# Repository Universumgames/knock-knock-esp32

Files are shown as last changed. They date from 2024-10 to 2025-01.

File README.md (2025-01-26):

# Klap-Klap

- [Klap-Klap](#klap-klap)
  - [Description](#description)
  - [Important files and directories](#important-files-and-directories)
  - [Contributing Setup](#contributing-setup)
  - [Project setup](#project-setup)

URL to repository: https://github.com/Universumgames/knock-knock-esp32

## Description
This project is a simple knock pattern recognizer for a door or chest. The knock pattern is stored on an SD card connected to the ESP32. The knock pattern is recognized by the ESP32 and if the pattern is correct, the door or chest is unlocked. The lock is controlled by a solenoid lock. The project is written in C with the ESP-IDF and uses the PlatformIO IDE. The project is based on the ESP32-C3 microcontroller.

## Important files and directories
- [`documentation/sprint_plan.md`](documentation/sprint_plan.md): Contains the Sprint Plan and detailed description by whom the task was completed
- [`documentation/backlog.md`](documentation/backlog.md): Contains the backlog, a detailed beakdown of the seperate task of this project
- [`src/`](src/): Contains the source code of the project
- [`test/`](test/): Contains the test code of the project
- [`platformio.ini`](platformio.ini): Contains the configuration of the project
- [`README.md`](README.md): Contains the description of the project
- [`LICENSE`](LICENSE): Contains the license of the project
- [`CHANGELOG.md`](CHANGELOG.md): The changelog 
- [`lib/`](lib/): Contains the self written libraries
- [`documentation/`](documentation/): Contains the documentation of the project
- [`datasheets/`](datasheets/): Contains the datasheets for the used components
- [`docker/`](docker/): Contains the docker files to build the platformio environment in a docker container
- [`pinout.txt`](pinout.txt): Contains the pinout of the used microcontroller
- [`pcb/`](pcb/): Contains the pcb files

## Contributing Setup
- install clang-format
  - Debian/Ubuntu: `sudo apt install clang-format`
  - Arch: `sudo pacman -S clang`
  - MacOS: `brew install clang-format`
  - Windows: `pip3 install clang-format`
- configure githooks
  - run `git config core.hooksPath .githooks`
- configure IDE to use clang-format
  - VS Code: install the `Clang-Format` extension (https://marketplace.visualstudio.com/items?itemName=xaver.clang-format)
  - CLion: enable clang-format (https://www.jetbrains.com/help/clion/clangformat-as-alternative-formatter.html)

## Project setup

1. Install VS Code
2. Install PlatformIO extension
3. open PIO Home -> Platforms -> Espressif 32 -> Install (should be installed automatically when opening the project via PlatformIO)
4. building the project by clicking on checkmark in the bottom left corner (when hovering over it, it says: "Build")
5. run tests via the `pio test` command in the terminal

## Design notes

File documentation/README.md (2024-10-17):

# Dokumentation Klopf-Klopf

# Inhalt
- [Product Summary](./produkt.md)
- [Sprint 1](./sprint_01.md)
- [Sprint 2](./sprint_02.md)
- [Sprint 3](./sprint_03.md)
- [Sprint 4](./sprint_04.md)
- [Sprint 5](./sprint_05.md)
- [Backlog](./backlog.md)
- [Sprintplan](./sprint_plan.md)
- [Schaltplan](./assets/circuit.pdf)
- [Timeline](#timeline)

## Timeline
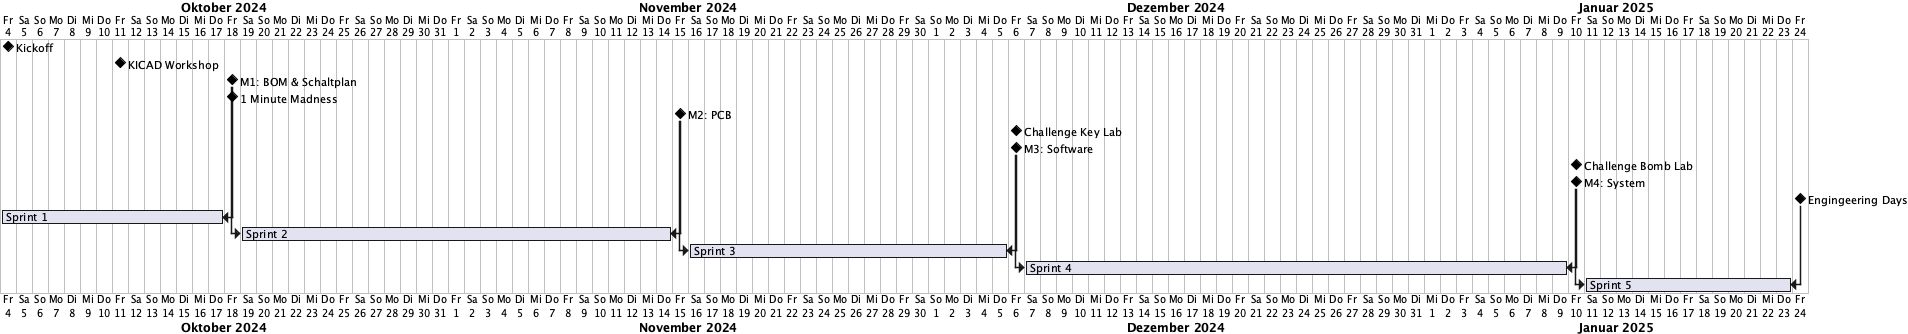
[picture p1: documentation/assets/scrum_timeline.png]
Scrum Timeline


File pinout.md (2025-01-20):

Used Pins:
- Storage: 4,5,6,7
- Onboard LED: 8
- Serial: 20, 21
- USB: (18,19)
- Solenoid: 3
- Piezo: 0
- Buttons: 
  - Up: 2
  - Down: 1
  - Record: 9
  - Delete: 10
  - Play: 19

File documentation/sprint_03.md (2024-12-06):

# Sprint Retro 3

## Kapitän: Jovan Arnaut

## Project Review

### Status

In diesem Sprint haben wir den Algorithmus für die Mustererkennung bzw. Encoden, welches aus dem vorherigen Sprint übrige geblieben war, fertigstellen können. 
Die Mustererkennung wurde auch mit Unit Test versehen und funktioniert soweit einwandfrei. Es ist jedoch noch nötig die Timings zu optimieren und die Thresholds zu justieren, welches eine Aufgabe für den nächsten Sprint sein wird. 
Über die Musteraufnahme und Erkennung hinaus haben wir auch die Musterwiedergabe implementiert. Sie soll später ermöglichen, dass die Muster, die aufgenommen wurden, auch wieder abgespielt werden können, damit sie später vom Nutzer auch gelöscht werden können.
Das Löschen der Muster wurde ebenfalls implementiert.
Der letzte Schritt in diesem Sprint war es die Musterverwaltung zu implementieren. Sie fügt die verschiedenen Funktionen, wie Musterwiedergabe, Löschen und Aufnahme zusammen und ermöglicht es dem Nutzer die aufgenommen Muster zu verwalten. Aufgrund von krankheitsfällen und anderweitigen zeitlich anspruchsvollen Aufgaben konnte die Musterverwaltung nicht vollständig implementiert werden und wird Aufgabe des nächsten Sprints werden.

### Offene Fragen zum Projekt

Im Sprint 3 sind keine weiteren Fragen für den Verlauf des Projektes aufgetreten. 

## Team Retrospektive

### Was hat im Team gut funktioniert?

Die Arbeitsweise im Team funktioniert einwandfrei. Die Aufgabenverteilung und die Zusammenarbeit bei der Besprechung und dem Review der Aufgaben hat gut funktioniert. 

### Was müssen wir an der Arbeitsweise des Teams ändern?

DIe Arbeit im Team hat gut funktioniert, an sich müssen wir nichts ändern. In der richtigen Wirtschaft, hätten wir uns als Team nur eventuell überlegen müssen, dass andere die Aufgaben übernehmen, damit wir durch Krankheitsfälle nicht in Verzug beim Kunden kommen, was jedoch in unserem Rahmen nicht Priorität hat.

### Was sollten wir nicht wiederholen?

In diesem Sprint gab es keine Problematiken, die nicht wiederholt werden dürfen.

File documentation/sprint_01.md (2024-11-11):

# Sprint Retro 1

## Einleitung
Mit dem Produkt Klopf-Klopf wollen wir eine Möglichkeit bieten, klassische Passwörter oder Schlösser durch ein System zur Identifizierung durch eindeutige Klopfmuster zu ersetzen.
Unser Produkt wird in einer Truhe verbaut, um die Funktionsweise handlich demonstrieren zu können. Weitere Informationen zu unserem Produkt sind der [Produktbeschreibung](./produkt.md) zu entnehmen.

---
## Ablauf Sprint 1

In unserem ersten Sprint für unsere Klopfmustererkennung mussten einige Schritte durchlaufen werden, um unsere Vision des Produktes so weit wie möglich zu realisieren. Zunächst haben wir eine detaillierte Projektplanung ([Backlog](./backlog.md)) ausgearbeitet, um einzelne Arbeitsschritte, Anforderungen und [Zeitpläne](./sprint_plan.md) für den weiteren Projektablauf festzulegen. Dies ermöglicht uns einen klaren Ablauf zu definieren und die Entwicklung des Produkts über die Wochen zu organisieren. 

Ein weiterer wesentlicher Bestandteil zu Beginn des Projektes war das Vertrautmachen mit der Entwicklungsumgebung, hier das ESP32-Framework sowie das Toolset [PlatformIO](https://platformio.org). 
Für den ersten Sprint war ebenfalls die Erstellung eines Schaltplans vorgesehen. Der Schaltplan für die Hardwarekomponenten wurde mit Hilfe der Software [KICAD](https://kicad.org) erstellt. Dieser Schaltplan hilft uns im weiteren Projektablauf, um die einzelnen elektronischen Komponenten, wie den Mikrocontroller, das Mikrofon, die LEDs und beispielsweise das Schloss, miteinander zu verbinden. 

In diesem Sprint fingen wir auch bereits mit der Umsetzung des Projektes an, wir bestellten benötigte Komponenten um Prototypen für die Mustererkennung auszuarbeiten. Um die Bauteile auf die Tauglichkeit für das Projekt zu testen und uns mit der ESP-IDF vertraut zu machen, haben wir bereits mit der Entwicklung der Software begonnen. Der zentrale Teil der Software im Sprint 1 war die Programmierung des LED-Drivers sowie des Storage-Drivers. Darüber hinaus implementierten wir die Steuerung für das Schloss unserer Holzbox, welches über ein Solenoid geöffnet und geschlossen wird. 

Um unser Projekt möglichst professionell zu präsentieren, haben wir eine [Präsentation](./one-minute-madness.pdf) erstellt, die unser Projekt in einer Minute anschaulich darstellen soll. Abschließend wurde eine umfassende Dokumentation verfasst, die sämtliche Arbeitsschritte, das Programmieren, die technische Umsetzung sowie die erzielten Ergebnisse beschreibt. Somit liegt unsere zweiwöchige Arbeit als Nachweis dar und dient als Grundlage für mögliche Erweiterungen des Projektes.

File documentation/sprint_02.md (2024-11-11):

# Sprint Retro 2

## Kapitän: Simon Vehreschild

## Project Review

### Status

In diesem Sprint haben wir die Platine entworfen, die Holzbox für unsere Präsentation gebaut, einen Notöffnungsmechanismus verschaltet und die Schloss Status LED implementiert. Die Mustererkennung und das Einspeichern der Muster wurden ebenfalls umgesetzt. Letztere zwei Punkte konnten jedoch aufgrund von zu optimistischer Planung sowie unerwarteten Problemen nicht vollständig abgeschlossen werden und müssen im nächsten Sprint 3 weiter bearbeitet werden.

Außerdem haben wir eine Spannungsversorgungsplatine, sowie eine Operationsverstärkerplatine entworfen, die für erste Testzwecke zum Einsatz gekommen sind.

### Offene Fragen zum Projekt

Im Sprint 2 sind keine weiteren Fragen für den Verlauf des Projektes aufgetreten. 

## Team Retrospektive

### Was hat im Team gut funktioniert?

Sowohl die Aufgabenverteilung als auch die Zusammenarbeit bei der Besprechung und dem Review der Aufgaben hat einwandfrei funktioniert. 
Wir haben uns gut abgestimmt und konnten effizient arbeiten. 
Im Team haben wir uns gegenseitig unterstützt und konnten so die Aufgaben gut bewältigen.

### Was müssen wir an der Arbeitsweise des Teams ändern?

Die Arbeitsweise des Teams verfolgt weiterhin die gesetzen Ziele der folgenden Sprints und muss somit nichts ändern. 

### Was sollten wir nicht wiederholen?

Die Planung der Aufgaben sollte realistischer gestaltet werden, um die Aufgaben besser abschließen zu können. Andererseits stoßen wir auf unerwartete Hindernisse, die nicht immer vorhersehbar sind.

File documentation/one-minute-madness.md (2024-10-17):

# Text für die Präsentation

Sehr geehrte Damen und Herren, bei unserem Produkt handelt es sich um ein Gerät zur Klopfmustererkennung. Der Produktname ist Klopf-Klopf

---

Wir präsentieren Ihnen ein System zur Identifizierung und Türöffnung durch eindeutige Klopfmuster.

Unser Produkt wird über ein revolutionäres Sensorsystem verfügen, mit welchem Klopfmuster erkannt und mit aufgenommenen Mustern verglichen werden können.

Diese Produktidee ist ein universelles Konzept und anwendbar für unzählige andere Anwendungen:

Zum Beispiel: Türschlösser, Tresore, alternative zu Fingerabdrucksensoren, optimal für Kinder

Da sie oft dazu neigen Gegenstände, wie Schlüssel, zu verlieren.

Klopf Klopf ist also die perfekte Alternative für Passwörter und Schlösser, um Ihre Wertsachen sicher aufzubewahren.

---
Wenn Zeit: Prototyp auf Bild zeigen

Vielen Dank für Ihre Aufmerksamkeit

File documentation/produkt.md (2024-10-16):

# Produkt

## Titel des Projekts: Klopf-Klopf (Topic 6 - Team B: Klopfmuster-Erkennung)

## Teammitglieder
- Jovan Arnaut: 1544440 
- Tom Arlt: 1335730
- Simon Vehreschild: 1543175

## Motivation
Ziel dieses Projektes ist es, den Umgang mit dem ESP32 und anderen elektrischen Komponenten zu erlernen und die grundlegende Funktionsweise des Mikrocontrollers zu verstehen. Außerdem wollen wir im Laufe des Projektes die Programmiersprache Assembler nachvollziehen und anwenden können.

## Beschreibung
Mit diesem Produktprototypen soll es möglich sein Klopfmuster zu erkennen und darauf zu reagieren. Es sollen Klopfmuster eingespeichert werden können, welche dann vom ESP32 wiedererkannt werden. Bei Erkennung eines eingespeicherten Klopfmusters soll das Schloss entriegelt werden. Da es für die Präsentation schwierig werden würde eine Tür zu verwenden, werden wir die Kopfmustererkennung nutzen, um eine Truhe zu entriegeln.

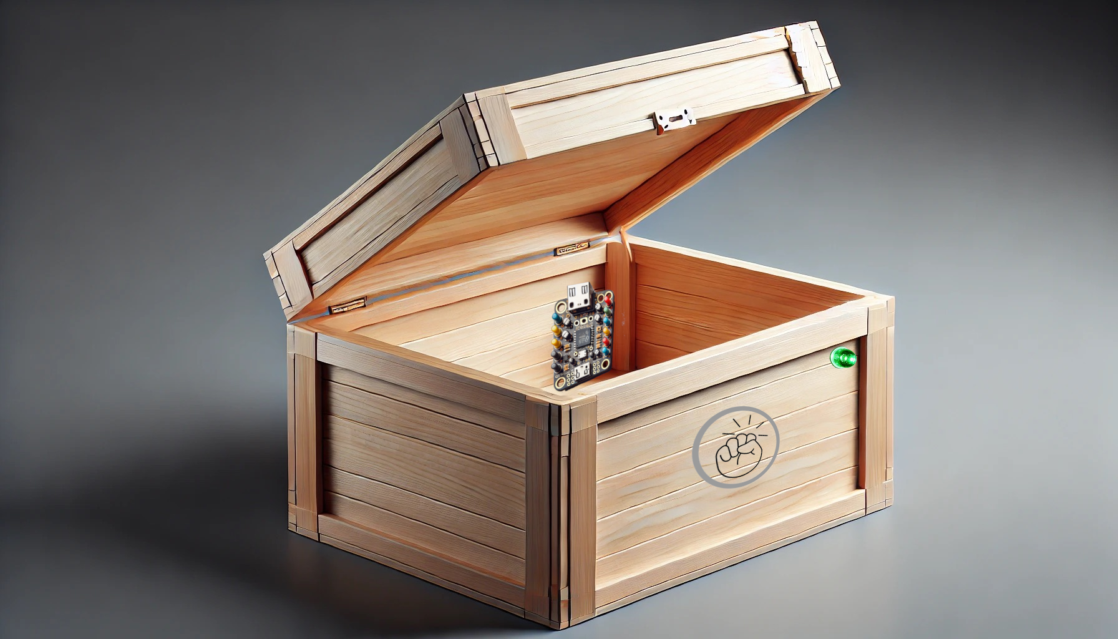
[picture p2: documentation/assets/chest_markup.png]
Produkt Abbildung


## Evaluation
Unser Produkt, die Klopfmustererkennung, ist in einer Truhe verbaut, die entriegelt wird, wenn das richtige Klopfmuster erkannt wird. Die Truhe ist mit einem Solenoid Schloss versehen, das durch den ESP32 gesteuert wird.
Die Funktionen, die bei unserem Produkt ausprobierbar sind, beinhalten das Einspeichern von neuen Klopfmustern, das Löschen von gespeicherten Klopfmustern, das Erkennen von Klopfmustern und das daraus folgende Öffnen des Schlosses. Das Schloss soll durch jeden geöffnet werden können, der eine der eingespeicherten Klopfmuster kennt. 

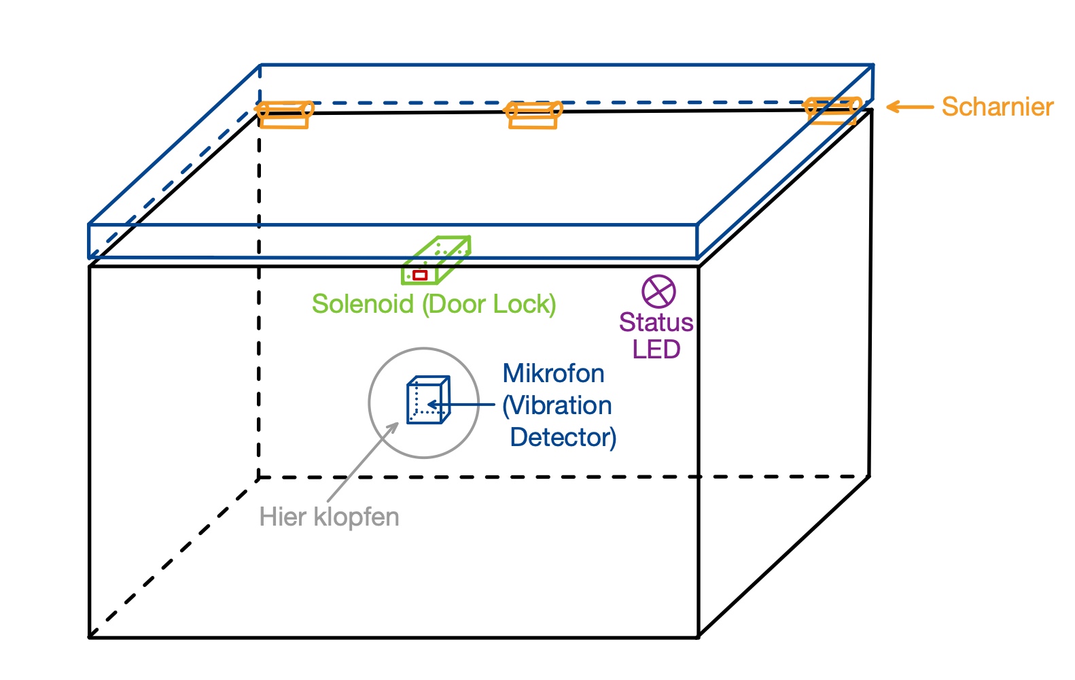
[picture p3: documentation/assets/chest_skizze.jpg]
Produkt Skizze


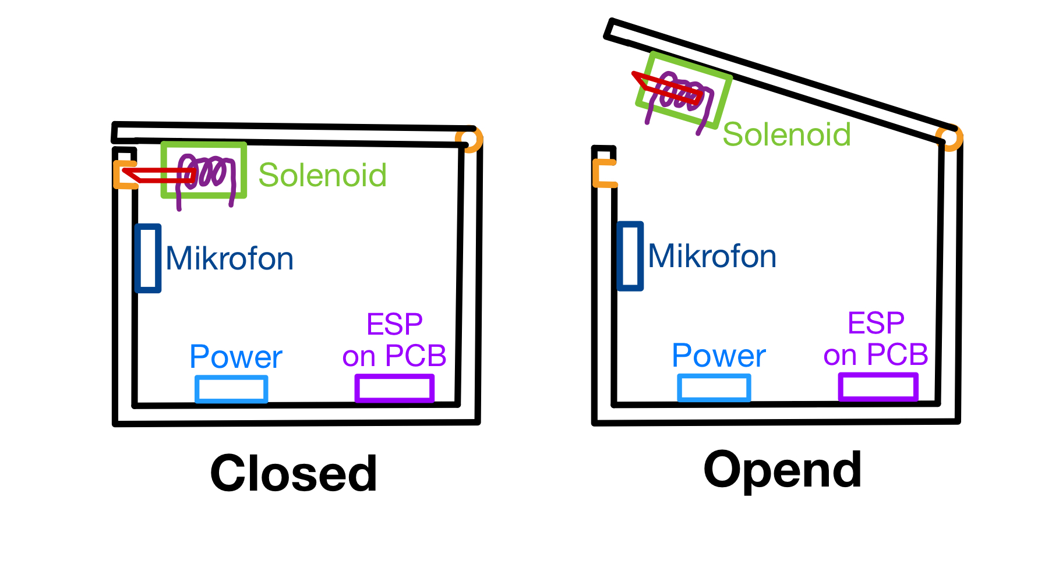
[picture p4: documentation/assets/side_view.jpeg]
Seitenansicht


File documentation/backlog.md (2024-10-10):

# Backlog
### Inhaltsverzeichnis

- [Backlog](#backlog)
    - [Inhaltsverzeichnis](#inhaltsverzeichnis)
    - [Erster Entwurf](#erster-entwurf)
  - [Aufgabe: Planung des Projekts](#aufgabe-planung-des-projekts)
    - [Beschreibung](#beschreibung)
- [Software Backlog](#software-backlog)
  - [Aufgabe: Vertrautmachen mit der Entwicklungsumgebung](#aufgabe-vertrautmachen-mit-der-entwicklungsumgebung)
    - [Beschreibung](#beschreibung-1)
  - [Aufgabe: Umsetzung der Mustererkennung](#aufgabe-umsetzung-der-mustererkennung)
    - [Beschreibung](#beschreibung-2)
    - [Definition von „Spaß“](#definition-von-spaß)
    - [Akzeptanzkriterien](#akzeptanzkriterien)
  - [Aufgabe: Muster einspeichern](#aufgabe-muster-einspeichern)
    - [Beschreibung](#beschreibung-3)
    - [Definition von „Spaß“](#definition-von-spaß-1)
    - [Akzeptanzkriterien](#akzeptanzkriterien-1)
  - [Aufgabe: Musteraufnahme](#aufgabe-musteraufnahme)
    - [Beschreibung](#beschreibung-4)
    - [Akzeptanzkriterien](#akzeptanzkriterien-2)
  - [Aufgabe: Muster löschen](#aufgabe-muster-löschen)
    - [Beschreibung](#beschreibung-5)
    - [Akzeptanzkriterien](#akzeptanzkriterien-3)
  - [Aufgabe: Schloss öffnen](#aufgabe-schloss-öffnen)
    - [Beschreibung](#beschreibung-6)
    - [Akzeptanzkriterien](#akzeptanzkriterien-4)
  - [Aufgabe: Musterverwaltung](#aufgabe-musterverwaltung)
    - [Beschreibung](#beschreibung-7)
    - [Akzeptanzkriterien](#akzeptanzkriterien-5)
  - [Aufgabe: Musterwiedergabe](#aufgabe-musterwiedergabe)
    - [Beschreibung](#beschreibung-8)
    - [Definition von „Spaß“](#definition-von-spaß-2)
    - [Akzeptanzkriterien](#akzeptanzkriterien-6)
  - [Aufgabe: Schloss Status LED](#aufgabe-schloss-status-led)
    - [Beschreibung](#beschreibung-9)
    - [Definition von „Spaß“](#definition-von-spaß-3)
    - [Akzeptanzkriterien](#akzeptanzkriterien-7)
  - [Aufgabe: Storage Driver](#aufgabe-storage-driver)
    - [Beschreibung](#beschreibung-10)
    - [Akzeptanzkriterien](#akzeptanzkriterien-8)
  - [Aufgabe: LED-Driver](#aufgabe-led-driver)
    - [Beschreibung](#beschreibung-11)
    - [Akzeptanzkriterien](#akzeptanzkriterien-9)
- [Hardware Backlog](#hardware-backlog)
  - [Aufgabe: Anfertigung der Holzbox](#aufgabe-anfertigung-der-holzbox)
    - [Beschreibung](#beschreibung-12)
    - [Definition von „Spaß“](#definition-von-spaß-4)
    - [Akzeptanzkriterien](#akzeptanzkriterien-10)
  - [Aufgabe: Solenoid (Door-Lock)](#aufgabe-solenoid-door-lock)
    - [Beschreibung](#beschreibung-13)
    - [Akzeptanzkriterien](#akzeptanzkriterien-11)
  - [Aufgabe: Drucktaster](#aufgabe-drucktaster)
    - [Beschreibung](#beschreibung-14)
    - [Akzeptanzkriterien](#akzeptanzkriterien-12)
  - [Aufgabe: RGB-LED (WS2812b)](#aufgabe-rgb-led-ws2812b)
    - [Beschreibung](#beschreibung-15)
    - [Definition von „Spaß“](#definition-von-spaß-5)
    - [Akzeptanzkriterien](#akzeptanzkriterien-13)
  - [Aufgabe: Notöffnungsmechanismus](#aufgabe-notöffnungsmechanismus)
    - [Beschreibung](#beschreibung-16)
    - [Akzeptanzkriterien](#akzeptanzkriterien-14)
  - [Aufgabe: Mikrofon](#aufgabe-mikrofon)
    - [Beschreibung](#beschreibung-17)
    - [Definition von „Spaß“](#definition-von-spaß-6)
    - [Akzeptanzkriterien](#akzeptanzkriterien-15)
  - [Aufgabe: Spannungsversorgung](#aufgabe-spannungsversorgung)
    - [Beschreibung](#beschreibung-18)
    - [Akzeptanzkriterien](#akzeptanzkriterien-16)
  - [Aufgabe: Platine entwerfen](#aufgabe-platine-entwerfen)
    - [Beschreibung](#beschreibung-19)
    - [Akzeptanzkriterien](#akzeptanzkriterien-17)
  - [Aufgabe: Fertigstellen des Systems](#aufgabe-fertigstellen-des-systems)
    - [Beschreibung](#beschreibung-20)
    - [Akzeptanzkriterien](#akzeptanzkriterien-18)
  - [Aufgabe: Erstellen eines Videos](#aufgabe-erstellen-eines-videos)
    - [Beschreibung](#beschreibung-21)
    - [Akzeptanzkriterien](#akzeptanzkriterien-19)
  - [Aufgabe: Erstellen des Kaufpitch](#aufgabe-erstellen-des-kaufpitch)
    - [Beschreibung](#beschreibung-22)
    - [Akzeptanzkriterien](#akzeptanzkriterien-20)

### Erster Entwurf

Features:
- Software:
    - [Mustererkennung](#aufgabe--umsetzung-der-mustererkennung)
    - [Muster einspeichern](#aufgabe--muster-einspeichern)
    - [Musteraufnahme](#aufgabe--musteraufnahme)
    - [Muster löschen](#aufgabe--muster-löschen)
    - [Schloss öffnen](#aufgabe--schloss-öffnen)
    - [Musterverwaltung](#aufgabe--musterverwaltung)
    - [Schloss Status LED](#aufgabe--schloss-status-led)
    - Dependency Features
      - [Musterwiedergabe](#aufgabe--musterverwaltung)
      - [Storage Driver](#aufgabe--storage-driver)
      - [LED Driver](#aufgabe--led-driver)

## Aufgabe: Planung des Projekts

### Beschreibung
Die Planung des Projekts umfasst die Aufteilung der Aufgaben in Sprints, die Zuweisung von Verantwortlichkeiten und die Schätzung des Zeitaufwands für die einzelnen Aufgaben. Sie dient dazu, das Projekt in überschaubare Teilaufgaben zu gliedern, erste Gedanken zu Umsetzung und diese im Nachhinein zu erleichtern.

## Aufgabe: Erstellen der Dokumentation

### Beschreibung
Kontinuierlich wird der Fortschritt des Projektes dokumentiert und die Dokumentation für jeden Sprint finalisiert.

### Akzeptanzkriterien
Die vollständige Dokumentation liegt vor.

## Aufgabe: Erstellen der 1 Minute Madness (PowerPoint)

### Beschreibung
In der "1 Minute Madness" haben wir genau eine Minute unsere Produktidee zu präsentieren. Dafür wollen wir eine PowerPoint-Präsentation erstellen.

### Akzeptanzkriterien
Die 1 Minute Madness ist präsentiert und im Vorhinein wurde eine PowerPoint-Präsentation erstellt.

# Software Backlog

## Aufgabe: Vertrautmachen mit der Entwicklungsumgebung 

### Beschreibung
Die Entwicklungsumgebung ist bisher für uns noch unbekannt, daher benötigt unser Team eine gewisse Zeit sich mit den Möglichkeiten vertraut zu machen.

## Aufgabe: Umsetzung der Mustererkennung

### Beschreibung
Die Mustererkennung sollte ähnliche Muster zuordnen können und ggf. bei zu großen Abweichungen des abgespeicherten Musters dies ausgeben. Die Schwierigkeit liegt dabei in der Verarbeitung des Mikrofonsignals und der Erkennung der Änderungen dieses Signal durch ein Klopfen. Anschließend soll das Muster mit den gespeicherten Mustern verglichen werden. Falls das Muster einem gespeicherten ähnelt, soll dies durch ein Öffnen des Verriegelungsmechanismus und der Grünen-LED zum Ausdruck gebracht werden.

### Definition von „Spaß“
Dies ist die Hauptherausforderung des gesamten Projekts und erfordert einen kreativen Lösungsansatz und eine gute Signalverarbeitung, da zwei Muster nie 100% identisch sein können.

### Akzeptanzkriterien
Der Mustererkennungs-Algorithmus soll in der Lage sein, das Muster durch das Rauschen zu erkennen und mit den eingespeicherten Mustern zu vergleichen. Anschließend soll bei einer gewissen Ähnlichkeit der Verriegelungsmechanismus und die Grüne-LED angesteuert werden können.

## Aufgabe: Muster einspeichern

### Beschreibung
Um die Muster zu speichern, müssen diese in ein simples und effizientes Format umgewandelt werden. Die Muster sollen in Dateien gespeichert werden, hierfür muss ein de-/serialisierungs-Algorithmus für die Muster geschrieben werden.

### Definition von „Spaß“
Wurde ein neues Muster aufgenommen, besteht die Herausforderung darin, dieses in ein Möglichst effizientes Format zu konvertieren und zu speichern. Dies garantiert eine schnelle und effiziente Mustererkennung und erfordert einiges an Kreativität und technischem Verständnis.

### Akzeptanzkriterien
Muster können gespeichert und abgerufen werden. Die Muster sind in einem effizienten Format gespeichert und können schnell und einfach abgerufen werden.

## Aufgabe: Musteraufnahme

### Beschreibung
Mit der Musteraufnahme ist das Aufnehmen und Filtern des Sensor-Signals gemeint. Das Mikrofon-Signal muss gefiltert und in ein verarbeitbares Format umgewandelt werden. Dieses Muster wird anschließend in der Mustererkennung sowie der Musterspeicherung verwendet. Für die Musteraufnahme kommt ein von der Musterverwaltung unabhängiger Knopf zum Einsatz.

### Akzeptanzkriterien
Störgeräusche wie Rauschen und andere Umgebungsgeräusche müssen gefiltert werden. Das Muster muss in einem effizienten Format als struct gespeichert werden und kann anschließend in der Mustererkennung verwendet werden um Muster zu vergleichen und einfacher zu speichern.

## Aufgabe: Muster löschen

### Beschreibung
Um die gespeicherten Muster von dem Flash-Speicher des ESP oder der SD-Karte entfernen zu können, muss eine Funktion im Speicher-Management implementiert werden, die das Löschen gespeicherter Mustert ermöglicht.

### Akzeptanzkriterien
Muster können nach dem Speichern auch gelöscht werden um neuen Speicherplatz zu schaffen.

## Aufgabe: Schloss öffnen

### Beschreibung
Die Kiste soll im Ruhezustand verschlossen und verriegelt sein. Sobald es (durch die Eingabe des korrekten Klopfmusters) gewünscht wird, soll das Solenoid die Falle (des Schlosses) zurück ziehen. Da das Solenoid nicht direkt durch den ESP mit Strom versorgt werden kann, kommt hier ein Relais zum Einsatz, welches mittels ESP angesteuert werden soll.

### Akzeptanzkriterien
Das Solenoid muss noch nicht angesteuert werden können. Es reicht aus, wenn das Relais umgeschaltet werden kann.

## Aufgabe: Musterverwaltung 

### Beschreibung
Die Musterverwaltung ermöglicht die Auswahl (Navigation) zwischen den einzelnen gespeicherten Mustern. Für die Muster gibt es zwei Funktionen: Muster löschen, Musterwiedergabe. Für die Musterverwaltung gibt es 4 Knöpfe: Vor, Zurück, Muster löschen, Musterwiedergabe. (Für das Aufnehmen von Mustern gibt es einen eigenständigen Knopf -> Musteraufnahme)

### Akzeptanzkriterien
Die Verwaltung sollte die einwandfreie Navigation durch die gespeicherten Muster ermöglichen, sowie den Aufruf der oben genannten Funktionen ausführen.

## Aufgabe: Musterwiedergabe

### Beschreibung

Die Musterwiedergabe soll die Möglichkeit bieten, ein gespeichertes Muster wiederzugeben. Dies ist wichtig, um die gespeicherten Muster zu überprüfen und zu löschen. Die Musterwiedergabe wird durch einen Drucktaster ausgelöst, der unabhängig von der Musterverwaltung ist. 

### Definition von „Spaß“
Interessant ist hier das gespeicherte Format eines Musters wieder in eine wiedererkennbare Form zu bringen und dieses Muster wiederzugeben.
Hierfür eine passende Darstellung zu finden und das Muster wiederzugeben ist eine kreative Herausforderung.

### Akzeptanzkriterien
Abgespeicherte Muster können wiedergegeben werden und sind in einer verständlichen Form dargestellt.

## Aufgabe: Schloss Status LED

### Beschreibung
An der Truhe befindet sich eine adressierbare LED (WS2812b) soll den Status des Schlosses anzeigen.
Die grundlegenden Status sind:
- Rot: Schloss ist verriegelt
- Grün: Schloss ist entriegelt
- Blau: aktuell wird ein Muster aufgenommen
- Orange: Muster ist fast korrekt
- Weiß: Fehlerfall

Unter Umständen müssen diese Status noch erweitert werden um weitere Informationen anzuzeigen, die erst im Laufe der Entwicklung aufgedeckt 
werden.

### Definition von „Spaß“
Interessant ist hier die Ansteuerung der LED anhand des Datenblatts zu analysieren und dieses eigene Protokoll im Code für die ESP-IDF zu entwickeln.

### Akzeptanzkriterien
Die LED zeigt den korrekten Status des Schlosses an.

## Aufgabe: Storage Driver

### Beschreibung
Der Storage Driver soll die Kommunikation zwischen Datenspeicher (on-board oder SD-Card) und dem ESP32 dienen.

### Akzeptanzkriterien
Dateien können korrekt erstellt und gelöscht werden.

## Aufgabe: LED-Driver

### Beschreibung
Der LED-Driver dient dazu die adressierbaren LEDs anzusteuern. Hierbei soll der Typ WS2812b verwendet werden und einfach, vergleichbar zu der FastLED Library, angesteuert werden können.

### Akzeptanzkriterien
Die LEDs können angesteuert werden und die Farbe wird für jede LED korrekt eingestellt.

# Hardware Backlog

## Aufgabe: Anfertigung der Holzbox

### Beschreibung
Um eine Tür zu demonstrieren, verwenden wir eine Box aus Holz, welche einen Doppelboden besitzt. Die Hardware-Komponenten werden in der verschlossenen Holzbox untergebracht. Der Doppelboden kann für die sichere und ordentliche Verkabelung der Komponenten genutzt werden, um Platz zu sparen und die Verdrahtung zu verstecken. 

### Definition von „Spaß“
Die Möglichkeit, ein eigenes und funktionales Produkt zu schaffen, trägt positiv zum Projekt bei. Der Prozess des Entwurfes und der Konstruktion der Holzbox bereichern die handwerklichen Fähigkeiten, die damit gefördert werden. 

### Akzeptanzkriterien
Die Aufgabe ist erledigt, wenn die Holzbox fertig montiert vorliegt und die jeweiligen Komponenten in der Box verbaut verden könnten. 

## Aufgabe: Solenoid (Door-Lock)

### Beschreibung
Um die Holzbox öffnen und schließen zu können wird ein Solenoid-Magnet als mechanischer Türverschluss verwendet. Der Mikrocontroller sendet ein Signal an das Solenoid, um die Tür jeweils zu verschließen oder zu entriegeln. Um das Solenoid vernünftig an die Holzbox anbringen zu können, wird eine Kerbe in die Wand gefräst. Die Ansteuerung des Solenoids erfolgt über ein Relais.

### Akzeptanzkriterien
Die Aufgabe ist erledigt, wenn die Tür mithilfe des Solenoids ohne Störungen verschlossen und entriegelt werden kann.

## Aufgabe: Drucktaster

### Beschreibung
Es werden mehrere Drucktaster eingerichtet, um Funktionen wie das Speichern, Navigieren und Löschen von Klopfmustern zu ermöglichen. Die jeweiligen Taster sind mit dem Mikrocontroller verbunden, der letztendlich die Eingaben verarbeitet. Die Taster müssen hardwaretechnisch entprellt werden.

### Akzeptanzkriterien
Die Aufgabe gilt als erledigt, wenn die Drucktaster am Gehäuse befestigt sind und ihre Funktionen in der Software erfüllen. 

## Aufgabe: RGB-LED (WS2812b)

### Beschreibung
Um den Status unseres Schlosses anzuzeigen, verwenden wir eine RGB-LED (WS2812b), welche wir zuvor konfigurieren. 

### Definition von „Spaß“
Die Herausforderung, die Ansteuerung der LED zu untersuchen und das entsprechende Datenblatt zu analysieren, um ein eigenes Protokoll im Code für die ESP_IDF zu erstellen.

### Akzeptanzkriterien
Die LED zeigt den korrekten Status des Schlosses an.

## Aufgabe: Notöffnungsmechanismus

### Beschreibung
Ein 12V-Kabel wird zum Solenoid geführt, um im Fehlerfall eine Notöffnung der Tür zu ermöglichen. Dies könnte durch einen Taster oder Schalter erfolgen, der unabhängig vom Mikrocontroller funktioniert. 

### Akzeptanzkriterien
Wenn das Schloss zu jeder Zeit oder bei Notfällen unabhängig vom Microcontroller geöffnet werden kann. Das Notöffnen des Schlosses sollte auch bei nicht vorhandener Platine und bei Softwareabsturz möglich sein.

## Aufgabe: Mikrofon

### Beschreibung
Es wird ein Mikrofon installiert, um die Klopfgeräusche und das dazugehörige Muster aufzuzeichnen. Das Mikrofon ist mit dem Microcontroller verbunden, welcher die Klopfgeräusche letztendlich analysiert, um ein Muster zu erkennen. 

### Definition von „Spaß“
Interessant ist hier die Ansteuerung des Mikrofons anhand des Datenblatts zu analysieren und die aufgenommenen Klopfgeräusche aufzunehmen und zu verwerten. 

### Akzeptanzkriterien
Die Funktion ist gegeben, wenn das Klopfgeräusch detektiert und weitergeleitet wird. 

## Aufgabe: Spannungsversorgung

### Beschreibung
Eine 12V (min. 1A) Spannungsversorgung wird verwendet, um das Solenoid und den Mikrocontroller (sowie alle anderen elektrischen Komponenten) mit Strom zu versorgen. Ein DC-DC Wandler wird eingesetzt, um die Spannung auf 5V zu reduzieren, die für den Mikrocontroller und andere elektrische Komponenten erforderlich ist.

### Akzeptanzkriterien
Die Spannungsversorgung ist fertig, wenn sowohl 12V, als auch 5V Spannungen abgegriffen werden können. Dies muss mittels Multimeter überprüft werden können.

## Aufgabe: Platine entwerfen

### Beschreibung
In unserer Kiste sollen einige der elektrischen Komponenten kompakt auf einer Platine verbaut werden. Diese Platine designen wir im Laufe dieses Projektes selber. Die Platine soll zum einen die Schalter der Musterverwaltung, den ESP, sowie die Schnittstellen zu den anderen nicht auf der Platine verbauten Komponenten unterbringen.

### Akzeptanzkriterien
Wenn die Platine designed ist und die geforderten Funktionen erfüllt. Die produzierte Platine muss noch nicht vorliegen.

## Aufgabe: Fertigstellen des Systems

### Beschreibung
Gegen Ende des Projektes werden alle Komponenten in der Holzbox montiert und elektrisch verkabelt. Softwarekomponenten sind alle zusammengeschaltet und einsatzbereit.

### Akzeptanzkriterien
Das gesamte System ist als Einheit funktionsfähig.

## Aufgabe: Erstellen eines Videos

### Beschreibung
Die Funktionen des Systems werden mittels Video beleuchtet. 

### Akzeptanzkriterien
Das Video ist erstellt und mit ggf. Text und Ton auf einem Endgerät darstellbar.

## Aufgabe: Erstellen des Kaufpitch

### Beschreibung
Die Funktionen des Systems sollen von Externen getestet werden können. Es wird über ein Verkaufskonzept nachgedacht.

### Akzeptanzkriterien
Ein Verkaufskonzept liegt vor.

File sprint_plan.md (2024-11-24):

# Plan Sprint Klopf-Klopf

## Scrum Master: Tom Arlt

## Aufgabe 1: Einen aussagekräftigen Titel

### Verantworliches Teammitglied: Name

### Erwarteter Zeitaufwand: Stunden

### Beschreibung
Definieren Sie die Aufgabe so, dass die verantwortliche Person sie ausführen kann, ohne weitere Erklärungen zu benötigen. Definieren Sie alle Abhängigkeiten oder Informationen, die geklärt werden müssen. Definieren Sie, wie die Lösung aussehen muss, damit sie akzeptabel ist.

### Definition von „Spaß“
Bei der Programmierung einer Klopfmuster-Erkennung gibt es viele Aspekte, die die Aufgabe spannend und lehrreich machen können. 

### Definition von „erledigt“
Legen Sie die Bedingungen fest, unter denen die verantwortliche Person die Aufgabe als erledigt betrachten kann.

## Aufgabe 2: Wie in der Vorlage für Aufgabe 1

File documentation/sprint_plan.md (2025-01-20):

# Plan Sprint Klopf-Klopf

## Sprint 1 
Kapitän: Tom Arlt

- Planung des Projektes
  - Verantwortlicher: Jovan Arnaut, Tom Arlt, Simon Vehreschild
  - Zeitaufwand: 20 Stunden

- Vertrautmachen mit der Enwicklungsumgebung
  - Verantwortlicher: Jovan Arnaut, Tom Arlt, Simon Vehreschild
  - Zeitaufwand: 10 Stunden

- LED Driver
  - Verantwortlicher: Tom Arlt
  - Zeitaufwand: 8 Stunden

- Storage Driver:
  - Verantwortlicher: Tom Arlt
  - Zeitaufwand: 8 Stunden

- Schloss öffnen:
  - Verantwortlicher: Simon Vehreschild
  - Zeitaufwand: 3 Stunden
  
- Erstellen der One Minute Madness
  - Verantwortlicher: Jovan Arnaut, Tom Arlt, Simon Vehreschild
  - Zeitaufwand: 4 Stunden

- Erstellen der Dokumentation
  - Verantwortlicher: Jovan Arnaut, Tom Arlt, Simon Vehreschild
  - Zeitaufwand: 5 Stunden

## Sprint 2
Kapitän: Simon Vehreschild

- Musteraufnahme (und Komprimierung)
  - Verantwortlicher: Tom Arlt, Simon Vehreschild
  - Zeitaufwand: 15 Stunden

- Mustererkennung
  - Verantwortlicher: Tom Arlt, Simon Vehreschild
  - Zeitaufwand: 40 Stunden

- Platine entwerfen
  - Verantwortlicher: Jovan Arnaut
  - Zeitaufwand: 25 Stunden

- Muster einspeichern
  - Verantwortlicher: Jovan Arnaut, Tom Arlt
  - Zeitaufwand: 10 Stunden

- Anfertigen der Holzbox
  - Verantwortlicher: Simon Vehreschild
  - Zeitaufwand: 16 Stunden

- Notöffnungsmechanismus
  - Verantwortlicher: Simon Vehreschild
  - Zeitaufwand: 2 Stunden

- Schloss Status LED
  - Verantwortlicher: Simon Vehreschild
  - Zeitaufwand: 8 Stunden

- Erstellen der Dokumentation
  - Verantwortlicher: Jovan Arnaut, Tom Arlt, Simon Vehreschild
  - Zeitaufwand: 8 Stunden

## Sprint 3
Kapitän: Jovan Arnaut

- Musteraufnahme (und Komprimierung)
  - Verantwortlicher: Tom Arlt, Simon Vehreschild
  - Zeitaufwand: 15 Stunden

- Mustererkennung
  - Verantwortlicher: Tom Arlt, Simon Vehreschild
  - Zeitaufwand: 40 Stunden

- Muster löschen
  - Verantwortlicher: Tom Arlt
  - Zeitaufwand: 5 Stunden

- Musterwiedergabe
  - Verantwortlicher: Simon Vehreschild
  - Zeitaufwand: 10 Stunden

- Musterverwaltung: 
  - Verantwortlicher: Jovan Arnaut
  - Zeitaufwand: 10 Stunden

- Erstellen der Dokumentation
  - Verantwortlicher: Jovan Arnaut, Tom Arlt, Simon Vehreschild
  - Zeitaufwand: 5 Stunden

## Sprint 4
Kapitän: Tom Arlt

- Fertigstellen des Systems
  - Verantwortlicher: Simon Vehreschild, Jovan Arnaut, Tom Arlt
  - Zeitaufwand: 30 Stunden

- Feintuning der Mustererkennung
  - Verantwortlicher: Simon Vehreschild, Tom Arlt
  - Zeitaufwand: 20 Stunden

- Erstellen der Dokumentation
  - Verantwortlicher: Jovan Arnaut, Tom Arlt, Simon Vehreschild
  - Zeitaufwand: 5 Stunden

- Bugfixing und Feintuning der Parameter
  - Verantwortlicher: Tom Arlt, Simon Vehreschild, Jovan Arnaut
  - Zeitaufwand: 15 Stunden

## Sprint 5
Kapitän: Simon Vehreschild

- Erstellen eines Videos
  - Verantwortlicher: Jovan Arnaut, Tom Arlt, Simon Vehreschild
  - Zeitaufwand: 25 Stunden

- Erstellen der Dokumentation
  - Verantwortlicher: Jovan Arnaut, Tom Arlt, Simon Vehreschild
  - Zeitaufwand: 2 Stunden

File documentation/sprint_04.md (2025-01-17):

# Sprint Retro 4

## Kapitän: Tom Arlt

## Project Review

### Status

Zu Begin wurde die Implementierung der Musterverwaltung fertiggestellt, welche im vorherigen Sprint durch einen Krankheitsfall in Verzögerung kam. Parallel dazu wurde unsere vorgefertigte Platine vollständig mit den notwendigen Bauteilen bestückt und diese verlötet. Ergänzend dazu wurden an der bestehenden Holzbox hardwareseitige Anpassungen vorgenommen, wie beispielsweise das Hinzufügen einer weiteren Öffnung für einen USB-Debug-Anschluss und das Befestigen einer Halterung für den Doppelboden. Um den sensitiven Bereich für das Klopfen zu definieren, wurde eine Schablone mit einem 3D-Drucker gedruckt, wodurch unser gewünschtes Symbol auf die Holzbox gesprüht werden konnte. 
Nachdem die einzelnen Komponenten in unserem System soweit fertiggestellt wurden, konnte die Inbetriebnahme durchgeführt und die Integration getestet werden. Während den Entwicklungsarbeiten traten verschiedene Herausforderungen auf, die letztendlich erfolgreich gelöst wurden. Unter anderem wurde eine Freilaufdiode hinzugefügt, um die auftretenden hohen Induktionsspannungen des Solenoids kurzzuschließen. Es wurde außerdem ein Verdrahtungsfehler im Schaltplan, PCB und der gefertigten Platine behoben. Diese Korrektur wurde in den aktualisierten Entwürfen integriert. Zusätzlich wurden kleinere Softwareanpassungen vorgenommen, um die Funktionen der Musterverwaltung zu verfeinern und sicherzustellen, dass das System zuverlässiger funktioniert.  
Insgesamt konnte das Projekt erfolgreich abgeschlossen werden. Trotz der aufgetretenen Herausforderungen wurden die vorgenommenen Ziele alle erreicht. Das entwickelte System ist nun einsatzbereit und erfüllt die gestellten Anforderungen und Erwartungen.

### Offene Fragen zum Projekt

Im Sprint 4 sind keine weiteren Fragen für den Verlauf des Projektes aufgetreten. 

## Team Retrospektive

### Was hat im Team gut funktioniert?

Die Arbeitsweise im Team funktioniert einwandfrei. Die Aufgabenverteilung und die Zusammenarbeit bei der Besprechung und dem Review der Aufgaben hat gut funktioniert. 

### Was müssen wir an der Arbeitsweise des Teams ändern?

Die Arbeit im Team hat sehr gut funktioniert.

### Was sollten wir nicht wiederholen?

In diesem Sprint gab es keine Problematiken, die nicht wiederholt werden dürfen.

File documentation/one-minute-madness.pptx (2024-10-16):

## Klopfmuster- Erkennung Klopf-Klopf

Fach: Mikrocontroller, 3. Fachsemester
Teilnehmer: Tom Arlt, Simon Vehreschild, Jovan Arnaut

Quelle: ChatGPT, Dall-E

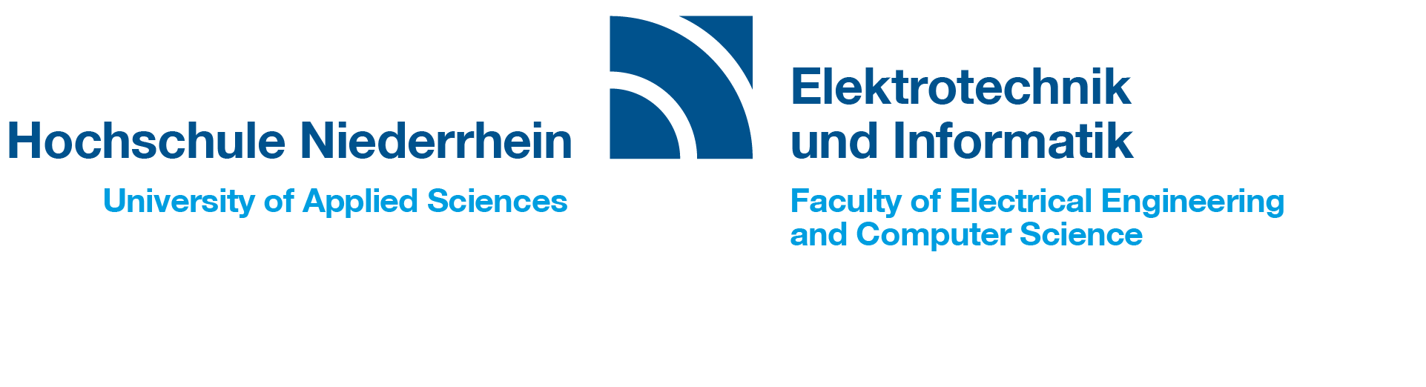
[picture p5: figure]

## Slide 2

Vision des Produkts

- System zur Identifizierung und Türöffnung durch eindeutige Klopfmuster
- über ein revolutionäres Sensorsystem können Klopfmuster erkannt und mit aufgenommenen Mustern verglichen werden
- Universelles Konzept – anwendbar für unzählige andere Anwendungsfälle
- Perfekte Alternative für Passwörter und Schlösser, um Wertsachen sicher aufzubewahren

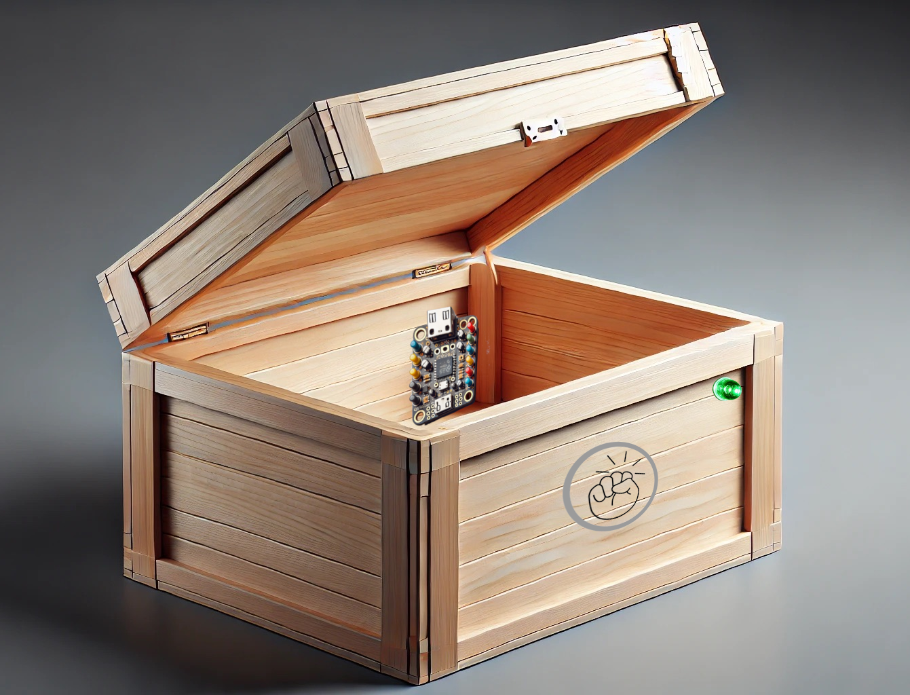
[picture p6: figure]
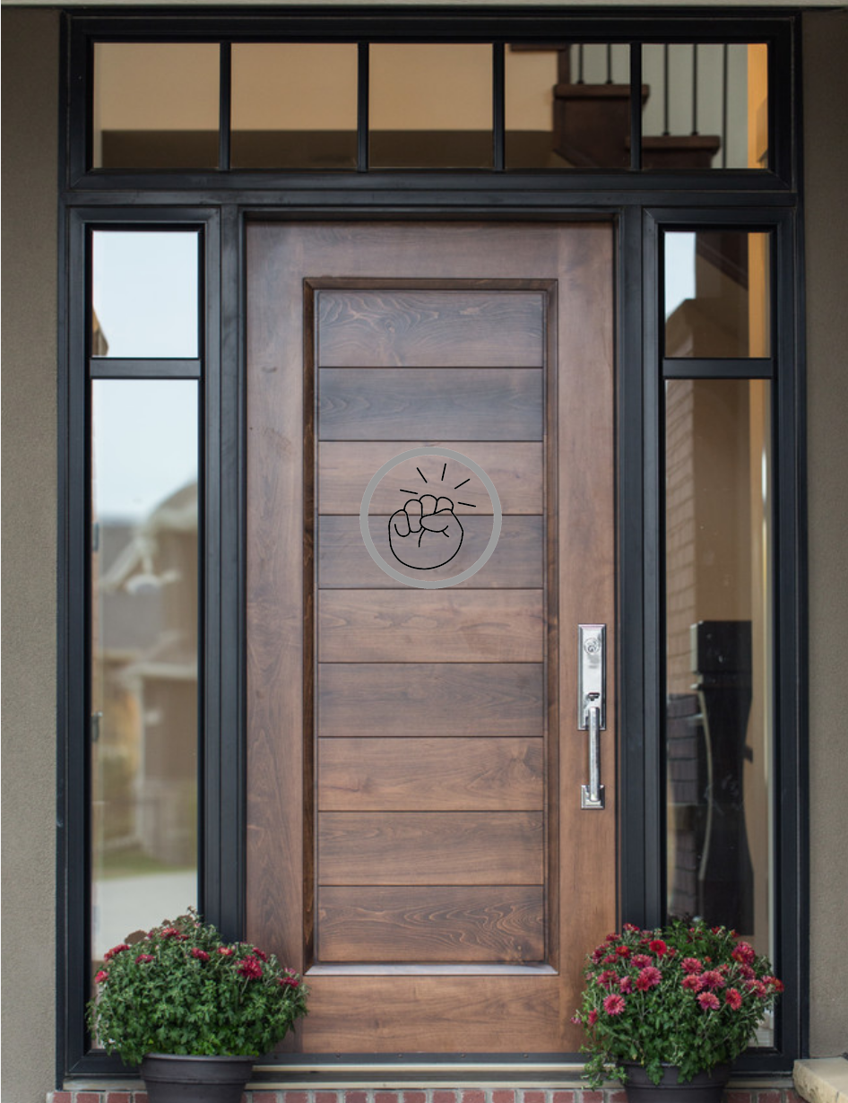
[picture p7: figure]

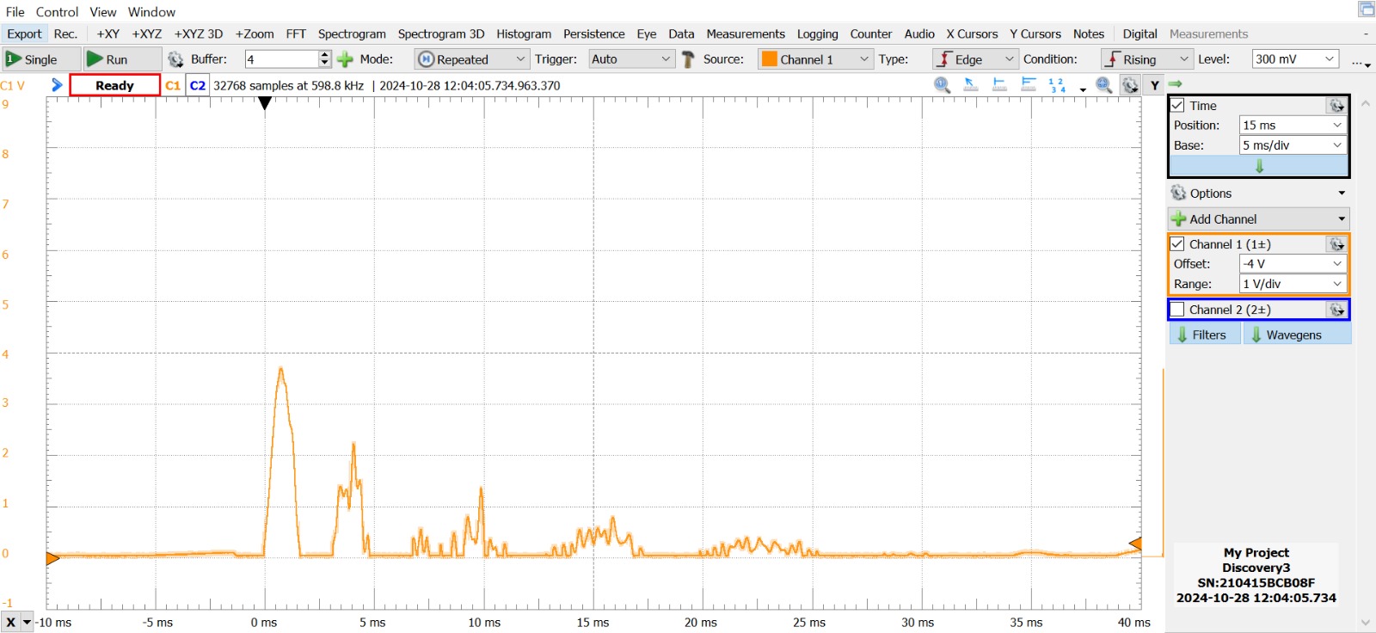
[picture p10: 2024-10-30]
documentation/assets/piezo_knocks/piezo_knock_wave_4.jpeg

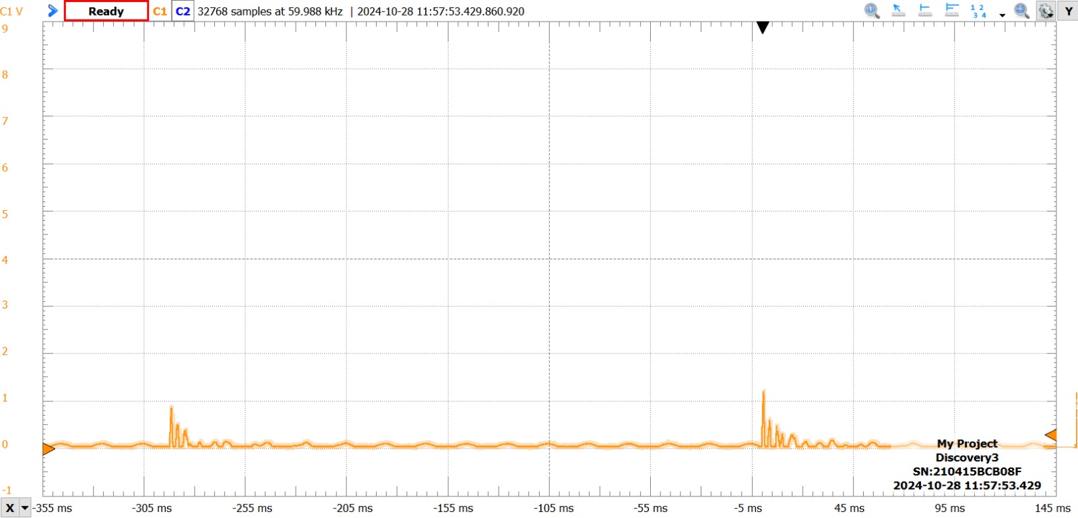
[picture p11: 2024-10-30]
documentation/assets/piezo_knocks/piezo_knock_wave_3.jpeg

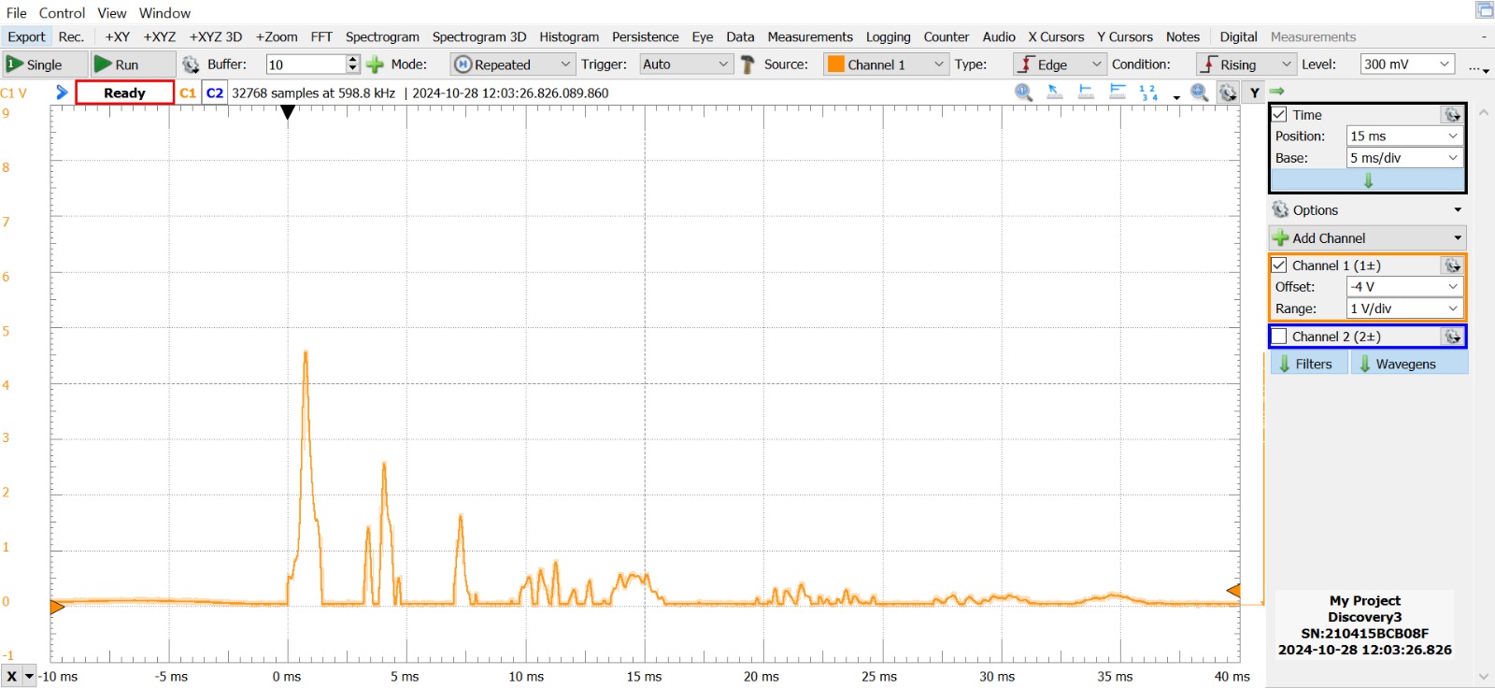
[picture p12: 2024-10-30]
documentation/assets/piezo_knocks/piezo_knock_wave_2.jpeg

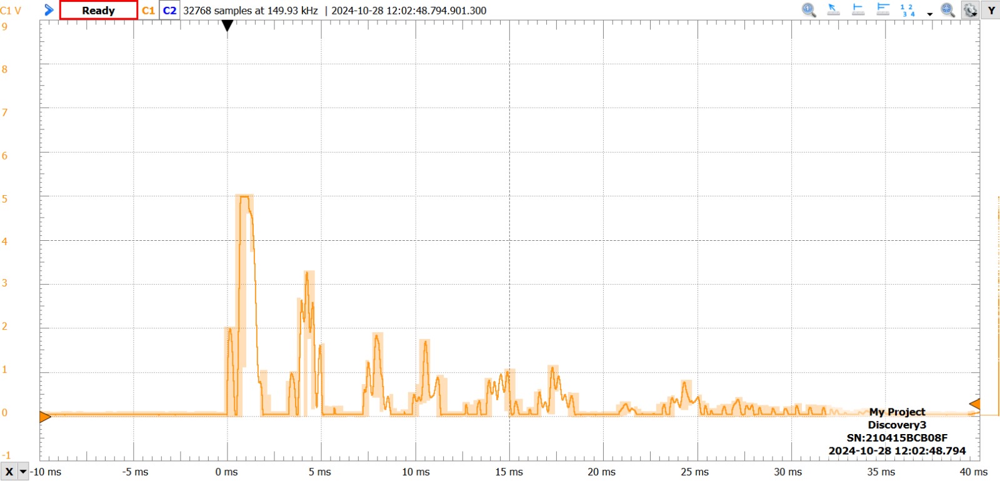
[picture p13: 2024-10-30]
documentation/assets/piezo_knocks/piezo_knock_wave_5.jpeg

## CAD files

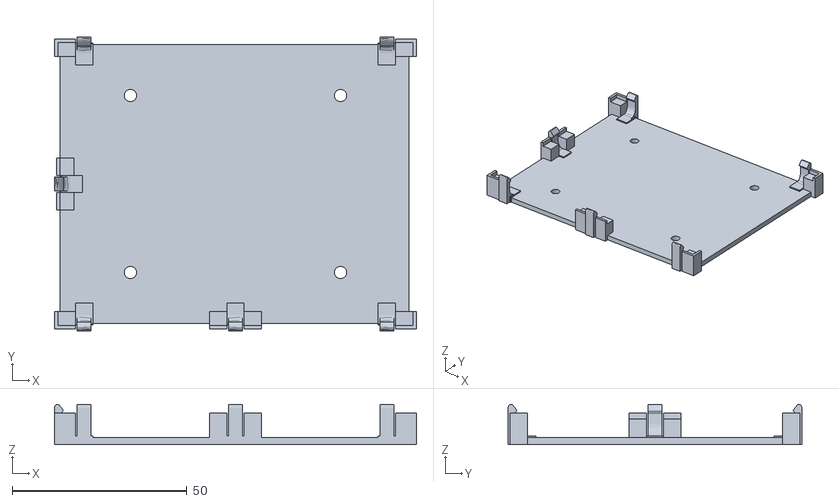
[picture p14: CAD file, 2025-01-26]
3d_prints/circuit_clamp_main.stl
103.7 x 84.2 x 11.5

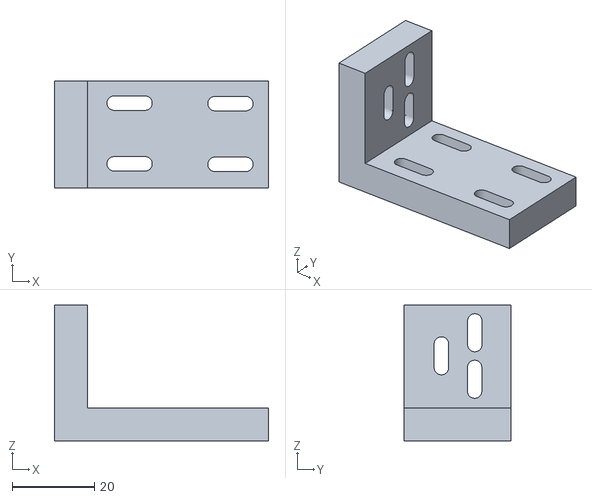
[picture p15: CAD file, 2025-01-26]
3d_prints/lock_latch_angle_mount.stl
52.0 x 26.0 x 33.0

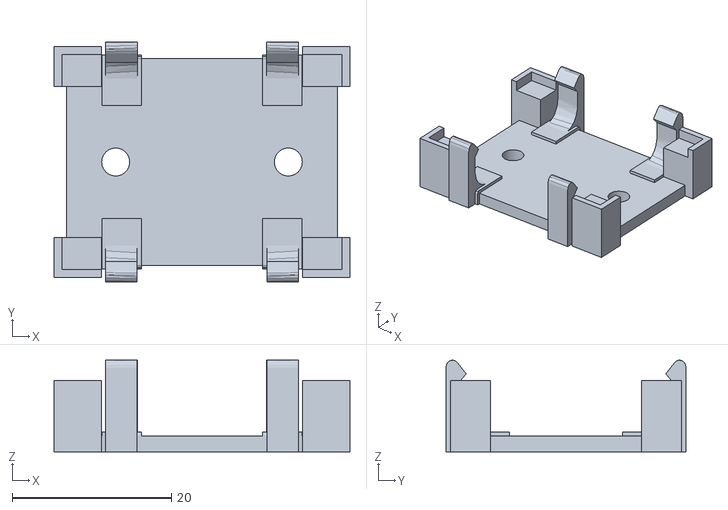
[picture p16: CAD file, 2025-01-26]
3d_prints/circuit_clamp_relais.stl
37.2 x 30.2 x 11.5

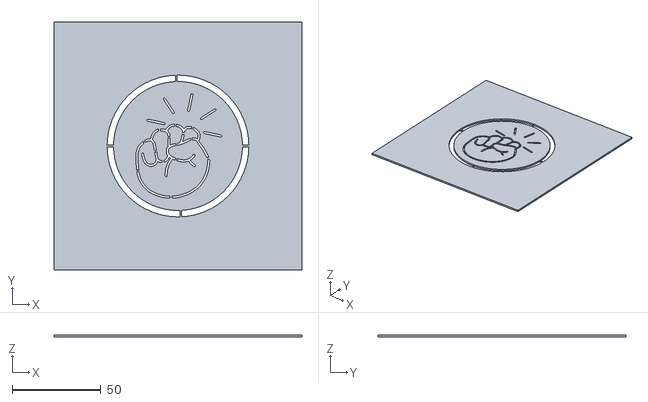
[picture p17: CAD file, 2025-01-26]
3d_prints/LOGO_MIC.stl
140.0 x 140.0 x 1.20

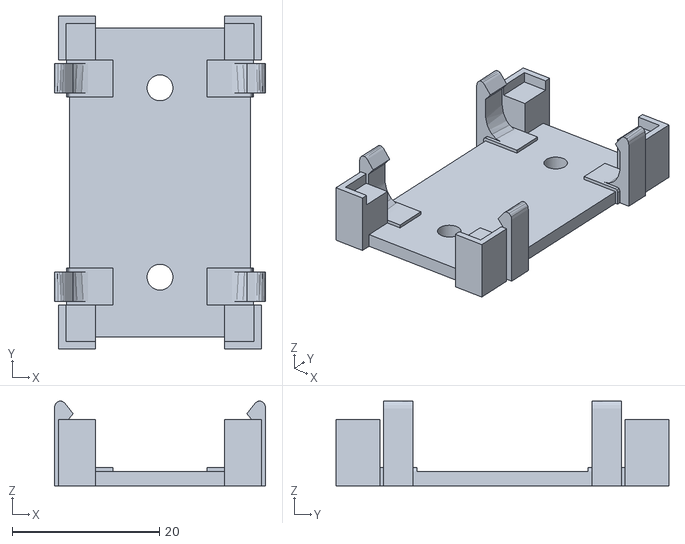
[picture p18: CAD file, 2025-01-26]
3d_prints/circuit_clamp_sdcard.stl
28.7 x 45.2 x 11.5

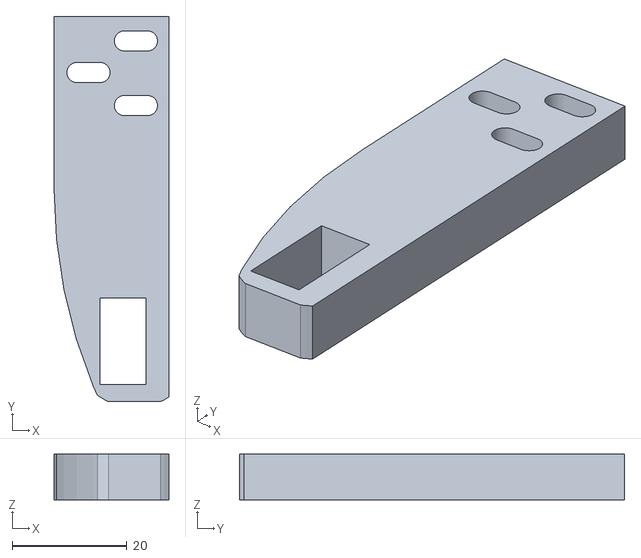
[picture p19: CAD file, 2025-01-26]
3d_prints/lock_latch.stl
20.0 x 67.0 x 8.00

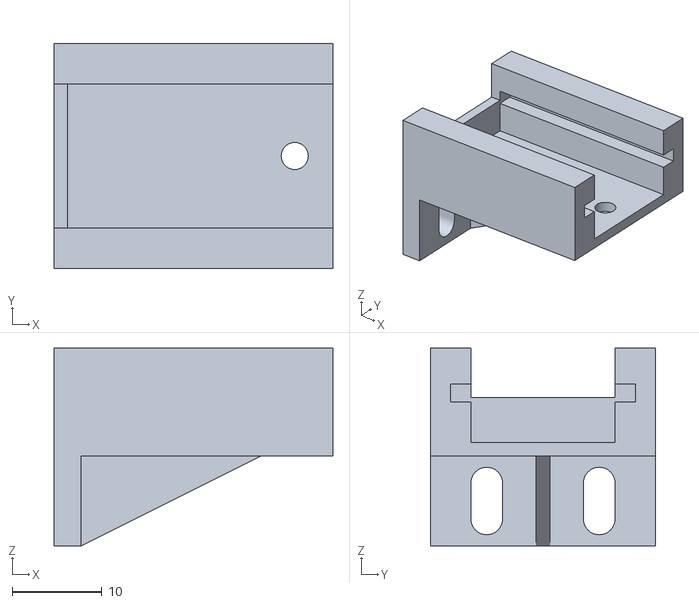
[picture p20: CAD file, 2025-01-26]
3d_prints/Power_Supply_Mounting.stl
31.0 x 25.0 x 22.0

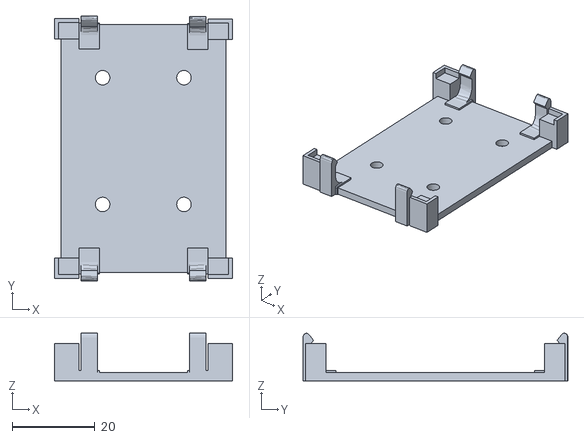
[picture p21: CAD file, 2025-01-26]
3d_prints/circuit_clamp_amplifier.stl
43.2 x 64.2 x 11.5

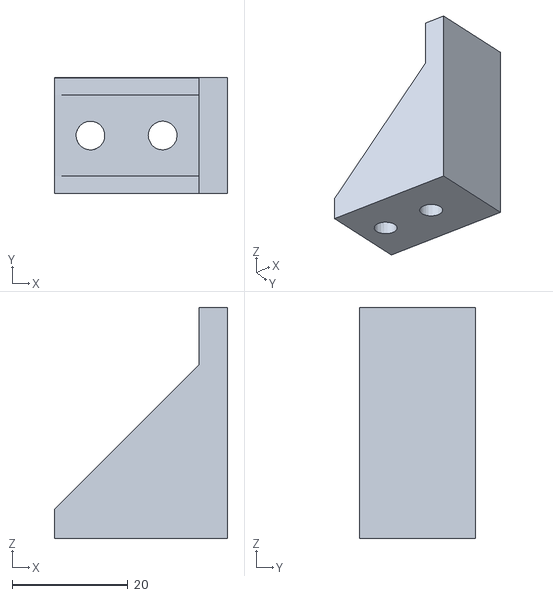
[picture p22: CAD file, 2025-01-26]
3d_prints/angle_mount_fake_floor.stl
30.0 x 20.0 x 40.0

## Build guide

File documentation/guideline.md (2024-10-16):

# Dokumentation Sprint Guideline

## Inhalt
- Text ....
- welche Schritte zur Reproduktion

## Anhang in Readme
- Backlog
- Sprints
- Schaltplan
- 3D-Modell
- (ggf.) Bilder

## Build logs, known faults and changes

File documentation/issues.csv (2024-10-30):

title | description | due_date | milestone
Planung des Projektes | Die Planung des Projekts umfasst die Aufteilung der Aufgaben in Sprints, die Zuweisung von Verantwortlichkeiten und die Schätzung des Zeitaufwands für die einzelnen Aufgaben. Sie dient dazu, das Projekt in überschaubare Teilaufgaben zu gliedern, erste Gedanken zu Umsetzung und diese im Nachhinein zu erleichtern. |  | BOM & Schaltplan
Vertrautmachen mit der Enwicklungsumgebung |  |  | BOM & Schaltplan
LED Driver |  |  | BOM & Schaltplan
Storage Driver |  |  | BOM & Schaltplan
Schloss öffnen |  |  | BOM & Schaltplan
Erstellen der One Minute Madness |  |  | BOM & Schaltplan
Erstellen der Dokumentation Sprint 1 |  |  | BOM & Schaltplan
Musteraufnahme (und Komprimierung) |  |  | PCB
Mustererkennung |  |  | PCB
Platine entwerfen |  |  | PCB
Muster einspeichern |  |  | PCB
Anfertigen der Holzbox |  |  | PCB
Notöffnungsmechanismus |  |  | PCB
Schloss Status LED |  |  | PCB
Erstellen der Dokumentation Sprint 2 |  |  | PCB
Muster löschen |  |  | Software
Musterwiedergabe |  |  | Software
Musterverwaltung |  |  | Software
Erstellen der Dokumentation Sprint 3 |  |  | Software
Fertigstellen des Systems |  |  | System
Erstellen eines Videos |  |  | Engineering Days
Erstellen des Kaufpitch |  |  | Engineering Days
Erstellen der Dokumentation Sprint 4 |  |  | System

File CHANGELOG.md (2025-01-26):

# Changelog
- ([a01efb8](https://git.ide3.de/universumgames/mic-projekt/-/commit/a01efb8b23990f4a6e3d581d785604724726ab35)) siveh001 on [2025-01-26](## "Sun, 26 Jan 2025 00:31:53 +0100") : update 3d prints
- ([779bcd3](https://git.ide3.de/universumgames/mic-projekt/-/commit/779bcd3e7dc9a0d5ab21f91674d646f1f4a435d6)) siveh001 on [2025-01-24](## "Fri, 24 Jan 2025 14:02:55 +0100") : adding pattern encoder reset debug log
- ([11ffe33](https://git.ide3.de/universumgames/mic-projekt/-/commit/11ffe33228d2ceff9ea967245f2ef551c7dade44)) joarn002 on [2025-01-20](## "Mon, 20 Jan 2025 11:35:55 +0100") : update sprint plan and readme
- ([cd08374](https://git.ide3.de/universumgames/mic-projekt/-/commit/cd083742735e00c5cf3adfcb40172784e5e79248)) Tom Arlt on [2025-01-20](## "Mon, 20 Jan 2025 10:33:41 +0000") : Merge branch 'recording-and-matching-fixing' into 'main'
- ([5391c4b](https://git.ide3.de/universumgames/mic-projekt/-/commit/5391c4b75337eedd8157a3d5855be4cf44b725f2)) Universumgames on [2025-01-20](## "Mon, 20 Jan 2025 11:25:01 +0100") : bugfixes
- ([eb05db2](https://git.ide3.de/universumgames/mic-projekt/-/commit/eb05db2c7c2adfaccbe80ee312f56d69052e60ec)) Universumgames on [2025-01-17](## "Fri, 17 Jan 2025 13:21:10 +0100") : uncomment management
- ([2b4080a](https://git.ide3.de/universumgames/mic-projekt/-/commit/2b4080a2562daca5866ca0177699384fcae1e494)) Universumgames on [2025-01-17](## "Fri, 17 Jan 2025 13:20:38 +0100") : add version hash
- ([7013eac](https://git.ide3.de/universumgames/mic-projekt/-/commit/7013eac1ad7b0750bc30768b47471e2b9af83501)) joarn002 on [2025-01-17](## "Fri, 17 Jan 2025 12:31:43 +0100") : Merge commit 'ee06e87d7b4baa23892cef55028fb3ea19ede206'
- ([ee06e87](https://git.ide3.de/universumgames/mic-projekt/-/commit/ee06e87d7b4baa23892cef55028fb3ea19ede206)) joarn002 on [2025-01-17](## "Fri, 17 Jan 2025 12:29:02 +0100") : Final Sprint4
- ([654df95](https://git.ide3.de/universumgames/mic-projekt/-/commit/654df95e4c53fd8d12cad5800f086949cdbca1e1)) Tom Arlt on [2025-01-17](## "Fri, 17 Jan 2025 11:17:04 +0000") : Merge branch 'Sprint-4' into 'main'
- ([9fc9d7b](https://git.ide3.de/universumgames/mic-projekt/-/commit/9fc9d7b0aa41037f68660336cb23b305b5bf3759)) joarn002 on [2025-01-15](## "Wed, 15 Jan 2025 23:36:27 +0100") : Sprint 4 Update
- ([d9ed498](https://git.ide3.de/universumgames/mic-projekt/-/commit/d9ed498de7e9c39f7a64830750d7db49dbba0ba7)) Tom Arlt on [2025-01-15](## "Wed, 15 Jan 2025 10:59:55 +0000") : Merge branch 'Update-PCB' into 'main'
- ([9b0ea3a](https://git.ide3.de/universumgames/mic-projekt/-/commit/9b0ea3ab78993f5aadb8a057238caef7f5ac9fcc)) joarn002 on [2025-01-14](## "Tue, 14 Jan 2025 14:36:22 +0100") : Finale Change PCB
- ([60b04c7](https://git.ide3.de/universumgames/mic-projekt/-/commit/60b04c7045623f344401285b44fcfeb5e494f90d)) joarn002 on [2025-01-13](## "Mon, 13 Jan 2025 20:16:10 +0100") : Change PCB/TEST
- ([169ed3e](https://git.ide3.de/universumgames/mic-projekt/-/commit/169ed3e36a8d705a5a01bd6566fc1a460eb4a6db)) joarn002 on [2025-01-13](## "Mon, 13 Jan 2025 20:13:48 +0100") : Schaltplanm
- ([70e9046](https://git.ide3.de/universumgames/mic-projekt/-/commit/70e9046aa21d6bf2cabd5776c275e6acd962c004)) siveh001 on [2025-01-13](## "Mon, 13 Jan 2025 19:21:27 +0100") : update lock OPENTIME
- ([5b58df3](https://git.ide3.de/universumgames/mic-projekt/-/commit/5b58df302d651c89018db62a85e6cae5f3b1193b)) Universumgames on [2025-01-13](## "Mon, 13 Jan 2025 17:55:32 +0100") : update trigger timeout
- ([7fb437e](https://git.ide3.de/universumgames/mic-projekt/-/commit/7fb437e1e2878075624be3e12f37a627531ba61c)) Universumgames on [2025-01-13](## "Mon, 13 Jan 2025 14:11:19 +0100") : bugfixes
- ([0e5e46d](https://git.ide3.de/universumgames/mic-projekt/-/commit/0e5e46d5a2fcdf5088b00d8e6bbe265bbb78c320)) Universumgames on [2025-01-13](## "Mon, 13 Jan 2025 13:33:59 +0100") : bugfixes
- ([7a1ea41](https://git.ide3.de/universumgames/mic-projekt/-/commit/7a1ea4139fd18cfafbed7307fbcfc9b34c157c9c)) Universumgames on [2025-01-13](## "Mon, 13 Jan 2025 12:30:10 +0100") : bugfixes for pattern deletion
- ([21d6a82](https://git.ide3.de/universumgames/mic-projekt/-/commit/21d6a821a930d9bc8e05e34bec31a47376094ea1)) Universumgames on [2025-01-13](## "Mon, 13 Jan 2025 12:11:25 +0100") : update brightness
- ([c6fe082](https://git.ide3.de/universumgames/mic-projekt/-/commit/c6fe082856ec5440f0ee6aa3a9450f3b6ca66434)) siveh001 on [2025-01-13](## "Mon, 13 Jan 2025 12:06:22 +0100") : update gitignore for kicad
- ([4f1936a](https://git.ide3.de/universumgames/mic-projekt/-/commit/4f1936a892fae19c68ce54f589a217b5efd0bdf1)) Universumgames on [2025-01-13](## "Mon, 13 Jan 2025 12:01:58 +0100") : fix recording
- ([4d987d1](https://git.ide3.de/universumgames/mic-projekt/-/commit/4d987d12aca9fbddf086559e8682bfe0ebb9b723)) Universumgames on [2025-01-13](## "Mon, 13 Jan 2025 11:38:09 +0100") : update command line
- ([91af50d](https://git.ide3.de/universumgames/mic-projekt/-/commit/91af50d39bdfccea6526d045dd9b866d47bbc446)) Universumgames on [2025-01-13](## "Mon, 13 Jan 2025 11:28:51 +0100") : update PatternManagement to autoplay
- ([711bf46](https://git.ide3.de/universumgames/mic-projekt/-/commit/711bf46cc7f34879e5092ef998f5dab4a3393bd0)) Universumgames on [2025-01-13](## "Mon, 13 Jan 2025 11:28:37 +0100") : fix deletion
- ([5ef6fe9](https://git.ide3.de/universumgames/mic-projekt/-/commit/5ef6fe986efddd6307e42f31a20a3cb07dde457a)) Universumgames on [2025-01-13](## "Mon, 13 Jan 2025 11:28:20 +0100") : update pins definition
- ([7b1c37d](https://git.ide3.de/universumgames/mic-projekt/-/commit/7b1c37d20a52a401980b64425895fcb3388c4cf1)) Universumgames on [2025-01-13](## "Mon, 13 Jan 2025 11:28:13 +0100") : add remove element method
- ([ad62f91](https://git.ide3.de/universumgames/mic-projekt/-/commit/ad62f9159d745fd353526e1d6e0771777c45468c)) Universumgames on [2025-01-12](## "Sun, 12 Jan 2025 22:27:20 +0100") : bomb lab files
- ([2142ca9](https://git.ide3.de/universumgames/mic-projekt/-/commit/2142ca97a7410c03cd0216734862d896483d66e9)) Universumgames on [2025-01-10](## "Fri, 10 Jan 2025 14:24:12 +0100") : bugfixes, adding new commands
- ([1e5b9f7](https://git.ide3.de/universumgames/mic-projekt/-/commit/1e5b9f717a9609f90c54e2996d730d3775f65e64)) Tom Arlt on [2024-12-29](## "Sun, 29 Dec 2024 01:14:12 +0000") : Merge branch '28-implement-a-simple-command-line-tool' into 'main'
- ([ef6e7ee](https://git.ide3.de/universumgames/mic-projekt/-/commit/ef6e7eeaa9297453423dba66cf436b8abe3645fc)) Universumgames on [2024-12-29](## "Sun, 29 Dec 2024 02:08:33 +0100") : disable all debug flags by default
- ([036818f](https://git.ide3.de/universumgames/mic-projekt/-/commit/036818f163baec4a51a59e1f5d42f098951d0682)) Universumgames on [2024-12-20](## "Fri, 20 Dec 2024 15:15:40 +0100") : fix unit test
- ([6ce4403](https://git.ide3.de/universumgames/mic-projekt/-/commit/6ce4403fd06219ae818813ce665b9073f55b4231)) Universumgames on [2024-12-20](## "Fri, 20 Dec 2024 14:57:00 +0100") : missed adding help entry for unlock
- ([8a5ed0e](https://git.ide3.de/universumgames/mic-projekt/-/commit/8a5ed0e822197245f6728abf0bcf7da984a777cd)) Universumgames on [2024-12-20](## "Fri, 20 Dec 2024 14:55:52 +0100") : rewrite to allow commands with arguments, string helper functions needed fixing
- ([eeb5c9a](https://git.ide3.de/universumgames/mic-projekt/-/commit/eeb5c9a2faad4db60a81a4b4f269bc00c16d5b96)) Universumgames on [2024-12-20](## "Fri, 20 Dec 2024 00:08:58 +0100") : fix flag header include
- ([b80ee31](https://git.ide3.de/universumgames/mic-projekt/-/commit/b80ee31038bf60261b75f09ca3c37c403389f492)) Universumgames on [2024-12-19](## "Thu, 19 Dec 2024 23:57:20 +0100") : add first draft of commands
- ([af3b91c](https://git.ide3.de/universumgames/mic-projekt/-/commit/af3b91c288550e825564653ba36de89e72902a0f)) Tom Arlt on [2024-12-16](## "Mon, 16 Dec 2024 09:34:29 +0000") : Merge branch '25-testat-01-tom' into 'main'
- ([b209c70](https://git.ide3.de/universumgames/mic-projekt/-/commit/b209c70dd2871194b6042fe8319a96a8bec87713)) siveh001 on [2024-12-13](## "Fri, 13 Dec 2024 16:49:01 +0100") : Simon und Jovan
- ([8ed5dbc](https://git.ide3.de/universumgames/mic-projekt/-/commit/8ed5dbc9f5ec180a35148c96cb14bd8149e74973)) Universumgames on [2024-12-13](## "Fri, 13 Dec 2024 16:31:12 +0100") : finished testat
- ([3d7b25b](https://git.ide3.de/universumgames/mic-projekt/-/commit/3d7b25b6349334d827615533846a3462f6a5e816)) Universumgames on [2024-12-13](## "Fri, 13 Dec 2024 14:34:09 +0100") : Merge branch 'main' into 25-testat-01-tom
- ([08fb26b](https://git.ide3.de/universumgames/mic-projekt/-/commit/08fb26befb89d9a7967e39cde2de7bc24c952a56)) Universumgames on [2024-12-12](## "Thu, 12 Dec 2024 22:06:13 +0100") : add testate template
- ([ce3a362](https://git.ide3.de/universumgames/mic-projekt/-/commit/ce3a362653af6e417e17509b221fc4c0e71969f7)) Universumgames on [2024-12-12](## "Thu, 12 Dec 2024 22:05:45 +0100") : add testate templates
- ([a126b9c](https://git.ide3.de/universumgames/mic-projekt/-/commit/a126b9c436e6e89dca7838ce0754f67f96590ac6)) Tom Arlt on [2024-12-11](## "Wed, 11 Dec 2024 10:42:44 +0000") : Merge branch 'feature-pattern-management' into 'main'
- ([2831f1d](https://git.ide3.de/universumgames/mic-projekt/-/commit/2831f1df3c33a8fc05067e5f9b499334c806bca5)) Universumgames on [2024-12-09](## "Mon, 9 Dec 2024 00:03:00 +0100") : fixed unit tests
- ([410cec8](https://git.ide3.de/universumgames/mic-projekt/-/commit/410cec826621a594d82b1d4fcec03a21037dbe3a)) Universumgames on [2024-12-06](## "Fri, 6 Dec 2024 15:51:52 +0100") : Merge remote-tracking branch 'origin/feature-pattern-management' into feature-pattern-management
- ([99e5a48](https://git.ide3.de/universumgames/mic-projekt/-/commit/99e5a48d307d1dc26e2967660db447c7727db78f)) Universumgames on [2024-12-06](## "Fri, 6 Dec 2024 15:51:33 +0100") : wrong tests moved
- ([f500d57](https://git.ide3.de/universumgames/mic-projekt/-/commit/f500d577b58cf532fe34f6cd33af5f5faeeebbc5)) Tom Arlt on [2024-12-06](## "Fri, 6 Dec 2024 14:24:46 +0000") : Merge branch 'main' into 'feature-pattern-management'
- ([632676c](https://git.ide3.de/universumgames/mic-projekt/-/commit/632676ce16ccb8d8ce43bd1a4369ce882c55b938)) Universumgames on [2024-12-06](## "Fri, 6 Dec 2024 15:24:18 +0100") : missed file
- ([00fbad1](https://git.ide3.de/universumgames/mic-projekt/-/commit/00fbad1f7cbbd6a37eab238c24eb577089ad04b0)) Universumgames on [2024-12-06](## "Fri, 6 Dec 2024 15:23:10 +0100") : refactoring, trying to add test
- ([7e69a26](https://git.ide3.de/universumgames/mic-projekt/-/commit/7e69a26ef940e0f52c1d6276e3b0be9ce9cd2d05)) Universumgames on [2024-12-06](## "Fri, 6 Dec 2024 14:46:39 +0100") : add numbertoString pragma
- ([b28b590](https://git.ide3.de/universumgames/mic-projekt/-/commit/b28b590542839ababc16819ea62b45f9b011ef9a)) Universumgames on [2024-12-06](## "Fri, 6 Dec 2024 14:30:28 +0100") : fix log
- ([3659db5](https://git.ide3.de/universumgames/mic-projekt/-/commit/3659db5f134715116a320101c4d0e79ad1c21c7e)) Universumgames on [2024-12-06](## "Fri, 6 Dec 2024 14:29:33 +0100") : bugfixes
- ([bb03ee5](https://git.ide3.de/universumgames/mic-projekt/-/commit/bb03ee5d7992a830b923734bcf11cc2cc88a7035)) svehreschild on [2024-12-06](## "Fri, 6 Dec 2024 13:28:23 +0000") : Merge branch '19-erstellen-der-dokumentation-sprint-3' into 'main'
- ([23721ce](https://git.ide3.de/universumgames/mic-projekt/-/commit/23721ce4ee7622c611f49f9b62abaf6cd20e7b7b)) joarn002 on [2024-12-05](## "Thu, 5 Dec 2024 20:39:59 +0100") : PatternManagmentdraft
- ([994c277](https://git.ide3.de/universumgames/mic-projekt/-/commit/994c2777cb02efae799f5ce648a399bb1babfc3c)) Universumgames on [2024-12-05](## "Thu, 5 Dec 2024 20:21:10 +0100") : update linked list to add prev
- ([8ec232c](https://git.ide3.de/universumgames/mic-projekt/-/commit/8ec232cb083a0d03237557a831d1705673c6be39)) Universumgames on [2024-12-05](## "Thu, 5 Dec 2024 19:48:56 +0100") : write retro, adjust sprint plan for next sprint
- ([1e217d8](https://git.ide3.de/universumgames/mic-projekt/-/commit/1e217d8fdd4cd9b19596d2837ad7ff7df70bb2ba)) Tom Arlt on [2024-12-04](## "Wed, 4 Dec 2024 11:49:54 +0000") : Merge branch 'main' into 'feature-pattern-management'
- ([8903ab0](https://git.ide3.de/universumgames/mic-projekt/-/commit/8903ab0d4f1143b16ad2785b63a968f446d5de71)) Universumgames on [2024-12-04](## "Wed, 4 Dec 2024 10:41:07 +0100") : add new gitignore entries
- ([37dff18](https://git.ide3.de/universumgames/mic-projekt/-/commit/37dff18784dbfc096ecabf309d318f8a91f46794)) Universumgames on [2024-12-04](## "Wed, 4 Dec 2024 10:40:55 +0100") : fix formatting
- ([48afa2b](https://git.ide3.de/universumgames/mic-projekt/-/commit/48afa2b193d875400d9141799a6ef214a676b8fd)) Universumgames on [2024-12-04](## "Wed, 4 Dec 2024 10:40:46 +0100") : fix assembler conventions
- ([f36bbc8](https://git.ide3.de/universumgames/mic-projekt/-/commit/f36bbc848fece2f69daccff08c871af543f9c841)) Tom Arlt on [2024-11-27](## "Wed, 27 Nov 2024 18:57:03 +0000") : Merge branch 'feature-pattern-play' into 'main'
- ([666f6bb](https://git.ide3.de/universumgames/mic-projekt/-/commit/666f6bb19dc74f1e1c72e6545efefd740d8a6b7f)) Tom Arlt on [2024-11-27](## "Wed, 27 Nov 2024 18:49:10 +0000") : Merge branch 'main' into 'feature-pattern-play'
- ([15a6aec](https://git.ide3.de/universumgames/mic-projekt/-/commit/15a6aec15a870fdc6dde10230679e42bc9027c8b)) siveh001 on [2024-11-27](## "Wed, 27 Nov 2024 15:51:30 +0100") : fertig
- ([83237cf](https://git.ide3.de/universumgames/mic-projekt/-/commit/83237cfa27bfa3e9b443a071db7117275b4eecde)) Universumgames on [2024-11-27](## "Wed, 27 Nov 2024 12:31:07 +0100") : create first rough outline for pattern management
- ([806ec46](https://git.ide3.de/universumgames/mic-projekt/-/commit/806ec46e5f99d68856d24271ec99664ad7f4c506)) Universumgames on [2024-11-27](## "Wed, 27 Nov 2024 12:15:57 +0100") : fix warnings in pragma
- ([c9da382](https://git.ide3.de/universumgames/mic-projekt/-/commit/c9da382b031da73ffbc5d12413b1b21a0150e27b)) Tom Arlt on [2024-11-27](## "Wed, 27 Nov 2024 11:07:59 +0000") : Merge branch 'feature-pattern-recognize' into 'main'
- ([931d451](https://git.ide3.de/universumgames/mic-projekt/-/commit/931d451ef37f855890fbd0ada18246e5e5abffc9)) Universumgames on [2024-11-27](## "Wed, 27 Nov 2024 11:35:40 +0100") : fix compile bugs
- ([065606f](https://git.ide3.de/universumgames/mic-projekt/-/commit/065606f4ab3b1728601ae35d831bada42c6c7b85)) Universumgames on [2024-11-27](## "Wed, 27 Nov 2024 11:29:00 +0100") : adding status check to recoder to match and store pattern
- ([4f21d47](https://git.ide3.de/universumgames/mic-projekt/-/commit/4f21d47d805eaa0c8085216ba2c2f674099f9b25)) Universumgames on [2024-11-27](## "Wed, 27 Nov 2024 11:08:17 +0100") : adding second pattern to matcher test
- ([e9c5ce5](https://git.ide3.de/universumgames/mic-projekt/-/commit/e9c5ce531708b1202a8bbd35c7e622fc42c9b7b3)) Universumgames on [2024-11-27](## "Wed, 27 Nov 2024 11:08:00 +0100") : bugfixes in llinked list
- ([84be22a](https://git.ide3.de/universumgames/mic-projekt/-/commit/84be22a7aa8a7ac0d1b621e8efff8629055e34be)) Universumgames on [2024-11-27](## "Wed, 27 Nov 2024 10:39:55 +0100") : add unit tests for play
- ([6e94a9b](https://git.ide3.de/universumgames/mic-projekt/-/commit/6e94a9b85d46fb0c98c3972234bddbc07513d584)) Universumgames on [2024-11-27](## "Wed, 27 Nov 2024 10:27:20 +0100") : add more test cases
- ([7042a96](https://git.ide3.de/universumgames/mic-projekt/-/commit/7042a96b0f73c9257ae3c56c4ffa2b7d6d14a44d)) siveh001 on [2024-11-26](## "Tue, 26 Nov 2024 09:07:02 +0100") : ready?
- ([4601c5e](https://git.ide3.de/universumgames/mic-projekt/-/commit/4601c5e1565d47ea9a885591d10f25737139d0ed)) Universumgames on [2024-11-26](## "Tue, 26 Nov 2024 00:24:18 +0100") : adding unit tests for matching, bugfixes
- ([7f7fa6c](https://git.ide3.de/universumgames/mic-projekt/-/commit/7f7fa6c4fcaed055d61cdbe1963af5d51251ec50)) siveh001 on [2024-11-25](## "Mon, 25 Nov 2024 17:44:57 +0100") : update
- ([89db4fa](https://git.ide3.de/universumgames/mic-projekt/-/commit/89db4fa147b4324ae3fbf0edb8b5ffc8b51a8f8e)) Universumgames on [2024-11-25](## "Mon, 25 Nov 2024 12:20:28 +0100") : fix multi instance ci/cd
- ([eb25ee5](https://git.ide3.de/universumgames/mic-projekt/-/commit/eb25ee587e6ab8e40efa793d348fd60ed80c40dd)) siveh001 on [2024-11-25](## "Mon, 25 Nov 2024 11:26:14 +0100") : update nochmal weitermachen
- ([eeac543](https://git.ide3.de/universumgames/mic-projekt/-/commit/eeac543a58281025c7c9e8e139cd8246582091d4)) Universumgames on [2024-11-25](## "Mon, 25 Nov 2024 11:21:56 +0100") : implement first draft of pattern matching
- ([74b6e8c](https://git.ide3.de/universumgames/mic-projekt/-/commit/74b6e8cdda62b65b812017458f96ad1bb9f6794e)) siveh001 on [2024-11-25](## "Mon, 25 Nov 2024 10:48:13 +0100") : start pattern_play
- ([bfa9880](https://git.ide3.de/universumgames/mic-projekt/-/commit/bfa988028dd70cf5577eeb60fdef526644dc55ea)) Tom Arlt on [2024-11-24](## "Sun, 24 Nov 2024 21:28:22 +0000") : Merge branch 'feature-pattern-record' into 'main'
- ([c59112f](https://git.ide3.de/universumgames/mic-projekt/-/commit/c59112f46fa42f836837f5e5c9cadfe4ae8e5981)) Tom Arlt on [2024-11-24](## "Sun, 24 Nov 2024 21:19:11 +0000") : Merge branch 'feature-pcb' into 'main'
- ([0d5cec2](https://git.ide3.de/universumgames/mic-projekt/-/commit/0d5cec23ba89017788fff9c470e3207ba3a2856b)) Universumgames on [2024-11-24](## "Sun, 24 Nov 2024 22:14:03 +0100") : refactoring, adding delta time warnings
- ([fbd126a](https://git.ide3.de/universumgames/mic-projekt/-/commit/fbd126a5e791f91753b7804b060cb9180a357c4b)) Universumgames on [2024-11-22](## "Fri, 22 Nov 2024 20:21:52 +0100") : fix types, fix one memory bug, update "nextID" generation, improve memory management, fix warnings
- ([41d2d6f](https://git.ide3.de/universumgames/mic-projekt/-/commit/41d2d6fdd8b2d711d971bcc28c305504905e952e)) Tom Arlt on [2024-11-20](## "Wed, 20 Nov 2024 11:59:04 +0000") : Merge branch 'main' into 'feature-pattern-record'
- ([dfc5623](https://git.ide3.de/universumgames/mic-projekt/-/commit/dfc56233d1b82b46d6b7265411b79d314d5f017c)) Universumgames on [2024-11-20](## "Wed, 20 Nov 2024 12:56:23 +0100") : some bugfixes
- ([447a657](https://git.ide3.de/universumgames/mic-projekt/-/commit/447a6574a2a06086005b5f2946f4593405364e9c)) Universumgames on [2024-11-20](## "Wed, 20 Nov 2024 10:52:59 +0100") : refactor to use cached linked lists for pattern storage
- ([cfe5a9e](https://git.ide3.de/universumgames/mic-projekt/-/commit/cfe5a9efb5b231471d2f54206def3fe639d4556b)) Universumgames on [2024-11-20](## "Wed, 20 Nov 2024 10:52:36 +0100") : fix warnings
- ([851c7b4](https://git.ide3.de/universumgames/mic-projekt/-/commit/851c7b4fd5868cc8812cc0b479905147f350735f)) Universumgames on [2024-11-20](## "Wed, 20 Nov 2024 10:51:58 +0100") : fix clang tidy
- ([92e4d6d](https://git.ide3.de/universumgames/mic-projekt/-/commit/92e4d6df0e384cbd3130696d507fb1e9e9eb8742)) Universumgames on [2024-11-20](## "Wed, 20 Nov 2024 09:25:21 +0100") : refactoring,
- ([08d29ce](https://git.ide3.de/universumgames/mic-projekt/-/commit/08d29ceb0b4e0a8619b6a7fd078a9fd17b7ad768)) joarn002 on [2024-11-18](## "Mon, 18 Nov 2024 21:01:32 +0100") : Finally
- ([629762e](https://git.ide3.de/universumgames/mic-projekt/-/commit/629762e65d459e6ce67dc44d33386f8aea2429d4)) joarn002 on [2024-11-18](## "Mon, 18 Nov 2024 20:58:37 +0100") : Finish
- ([607bb61](https://git.ide3.de/universumgames/mic-projekt/-/commit/607bb61218e85f35c050608b60ac8a35b32c7879)) joarn002 on [2024-11-18](## "Mon, 18 Nov 2024 20:29:54 +0100") : FertigEndgültig100x80mm
- ([eb1ae23](https://git.ide3.de/universumgames/mic-projekt/-/commit/eb1ae235b18353458f62870cb158dc7cd731f16c)) joarn002 on [2024-11-18](## "Mon, 18 Nov 2024 20:24:52 +0100") : Finish 100x80
- ([d2e0738](https://git.ide3.de/universumgames/mic-projekt/-/commit/d2e073813fc89ee85e8fbcbdd15d860140cc2d50)) Universumgames on [2024-11-17](## "Sun, 17 Nov 2024 23:43:37 +0100") : add assembly comments
- ([de28157](https://git.ide3.de/universumgames/mic-projekt/-/commit/de281571f9d0dc4822415b69bb2e55cdfda892f9)) Universumgames on [2024-11-17](## "Sun, 17 Nov 2024 23:37:44 +0100") : re-add file storing
- ([c671042](https://git.ide3.de/universumgames/mic-projekt/-/commit/c671042540e5fe20701c86c0d305dcbf8a94d6e0)) Universumgames on [2024-11-17](## "Sun, 17 Nov 2024 23:33:43 +0100") : fix loging issue
- ([5d1b351](https://git.ide3.de/universumgames/mic-projekt/-/commit/5d1b3515f5c8c6f0796cf4a66ed0412818f8f664)) Universumgames on [2024-11-17](## "Sun, 17 Nov 2024 23:33:20 +0100") : fix esp assembly
- ([2516384](https://git.ide3.de/universumgames/mic-projekt/-/commit/25163844ee4590f4ca8d8b88ace7c71933a49be9)) Universumgames on [2024-11-16](## "Sat, 16 Nov 2024 01:25:30 +0100") : fix compile
- ([8a36d8a](https://git.ide3.de/universumgames/mic-projekt/-/commit/8a36d8a1e80e76ca9429b151008e2ac40c42eca9)) Universumgames on [2024-11-16](## "Sat, 16 Nov 2024 00:23:59 +0100") : update pattern encoder
- ([63d0d00](https://git.ide3.de/universumgames/mic-projekt/-/commit/63d0d00b8221fe614c133f1a104fb00f5cb3abfe)) Universumgames on [2024-11-16](## "Sat, 16 Nov 2024 00:23:51 +0100") : add min function
- ([117297f](https://git.ide3.de/universumgames/mic-projekt/-/commit/117297f0d08be2f9b11a9b64d9f4e1c0bb43d6ef)) Universumgames on [2024-11-16](## "Sat, 16 Nov 2024 00:23:38 +0100") : use global pin definition
- ([56351da](https://git.ide3.de/universumgames/mic-projekt/-/commit/56351dada4414756aa7eae0dffae3d4082f2b10e)) joarn002 on [2024-11-13](## "Wed, 13 Nov 2024 18:06:45 +0100") : NochmalFinal
- ([e322663](https://git.ide3.de/universumgames/mic-projekt/-/commit/e322663364ee3ad531effb42bdec6f0e1cd84377)) joarn002 on [2024-11-13](## "Wed, 13 Nov 2024 17:03:14 +0100") : Finale_PCB???
- ([63304b6](https://git.ide3.de/universumgames/mic-projekt/-/commit/63304b622ff8075330dcf60ac4405edd8265f850)) joarn002 on [2024-11-13](## "Wed, 13 Nov 2024 16:21:38 +0100") : update
- ([c65aecf](https://git.ide3.de/universumgames/mic-projekt/-/commit/c65aecf05abe0946de4fa28797625c3323d02846)) joarn002 on [2024-11-12](## "Tue, 12 Nov 2024 00:00:38 +0100") : PCB-Update
- ([e9bf8e8](https://git.ide3.de/universumgames/mic-projekt/-/commit/e9bf8e81ac69185c09682d7bd9ff6557e4fea30f)) Universumgames on [2024-11-11](## "Mon, 11 Nov 2024 20:28:58 +0100") : finish retro sprint 2
- ([7d82214](https://git.ide3.de/universumgames/mic-projekt/-/commit/7d8221420ee78d44c28a2fffce6b67b20a127799)) Universumgames on [2024-11-11](## "Mon, 11 Nov 2024 20:05:04 +0100") : refactoring
- ([f5aa01b](https://git.ide3.de/universumgames/mic-projekt/-/commit/f5aa01b643ea27b4da1a9acd3d3411cdafd0c4a3)) joarn002 on [2024-11-11](## "Mon, 11 Nov 2024 11:42:16 +0100") : PCB Update
- ([f3d3db1](https://git.ide3.de/universumgames/mic-projekt/-/commit/f3d3db16b225dce26f7924c4140d5593d09e6142)) joarn002 on [2024-11-11](## "Mon, 11 Nov 2024 11:19:59 +0100") : verkabelung fertig
- ([4f60c7d](https://git.ide3.de/universumgames/mic-projekt/-/commit/4f60c7dc84d3d138077ab396dda009c8e65f2755)) joarn002 on [2024-11-11](## "Mon, 11 Nov 2024 10:23:34 +0100") : PCB update
- ([62586cf](https://git.ide3.de/universumgames/mic-projekt/-/commit/62586cf243ba6ebf202729d89a836cbf4058808e)) Universumgames on [2024-11-08](## "Fri, 8 Nov 2024 15:41:41 +0100") : bugfixes and preparing sprint retro
- ([2d5a2cd](https://git.ide3.de/universumgames/mic-projekt/-/commit/2d5a2cdce5b1bfad4c80fd359e235e49aad2f16f)) Universumgames on [2024-11-07](## "Thu, 7 Nov 2024 23:14:03 +0100") : fix unit tests
- ([bc12b02](https://git.ide3.de/universumgames/mic-projekt/-/commit/bc12b021220965f45291ba36961642f5a6f17ee9)) Universumgames on [2024-11-07](## "Thu, 7 Nov 2024 23:04:49 +0100") : add gitignore for old encoder tests
- ([48cd7ec](https://git.ide3.de/universumgames/mic-projekt/-/commit/48cd7ecef43b659950dafe297fac3ade155d8eb9)) Universumgames on [2024-11-07](## "Thu, 7 Nov 2024 23:04:22 +0100") : encoder tests
- ([dd17fbb](https://git.ide3.de/universumgames/mic-projekt/-/commit/dd17fbb015fbef4d9d53f559435d771e9784d6cf)) Universumgames on [2024-11-07](## "Thu, 7 Nov 2024 23:03:20 +0100") : increase maximum opened files
- ([eceb5f9](https://git.ide3.de/universumgames/mic-projekt/-/commit/eceb5f9defb33ad8514e467dc5d55fa353530a4e)) Universumgames on [2024-11-07](## "Thu, 7 Nov 2024 23:03:07 +0100") : continue with pattern encoder
- ([8f64b4b](https://git.ide3.de/universumgames/mic-projekt/-/commit/8f64b4b024da2a603d8dcfe862decbf47d5dc6ef)) Universumgames on [2024-11-07](## "Thu, 7 Nov 2024 23:02:30 +0100") : add thread prio header
- ([ba8fab1](https://git.ide3.de/universumgames/mic-projekt/-/commit/ba8fab1710113d1ebba23f83b322992b78d816a8)) Universumgames on [2024-11-07](## "Thu, 7 Nov 2024 23:02:07 +0100") : ring buffer fixes and added tests
- ([f35bbc6](https://git.ide3.de/universumgames/mic-projekt/-/commit/f35bbc676327295653ecf0b8b9bd34507d316b91)) Universumgames on [2024-11-07](## "Thu, 7 Nov 2024 02:05:05 +0100") : fix compile
- ([03d64da](https://git.ide3.de/universumgames/mic-projekt/-/commit/03d64dad07745754426b30ee4d325e5cf3eb279d)) Universumgames on [2024-11-07](## "Thu, 7 Nov 2024 01:44:43 +0100") : fix string test
- ([fb8e2e3](https://git.ide3.de/universumgames/mic-projekt/-/commit/fb8e2e39a2b6c4730b1f321638511326ee74f7f0)) Universumgames on [2024-11-07](## "Thu, 7 Nov 2024 01:43:06 +0100") : missing partition table
- ([0de0811](https://git.ide3.de/universumgames/mic-projekt/-/commit/0de0811782bec8077c69343b5dda2c6e952c22d7)) Universumgames on [2024-11-07](## "Thu, 7 Nov 2024 01:38:58 +0100") : fix 4mb flash
- ([f2d6fb1](https://git.ide3.de/universumgames/mic-projekt/-/commit/f2d6fb1f87ededa323b8ce1bd5ac5634554d1d6f)) Universumgames on [2024-11-07](## "Thu, 7 Nov 2024 01:38:12 +0100") : refactoring
- ([b29f7f9](https://git.ide3.de/universumgames/mic-projekt/-/commit/b29f7f9dbcacc173474911e1e16de23c828cf5cf)) Universumgames on [2024-11-07](## "Thu, 7 Nov 2024 01:22:49 +0100") : update pio file
- ([a081b70](https://git.ide3.de/universumgames/mic-projekt/-/commit/a081b706b3da3f33ea1caab2a22cfeca08247307)) Universumgames on [2024-11-07](## "Thu, 7 Nov 2024 01:21:55 +0100") : missing pio update
- ([0a72fc2](https://git.ide3.de/universumgames/mic-projekt/-/commit/0a72fc2ca654486e33fb4c6326cec5578aa8f266)) Universumgames on [2024-11-07](## "Thu, 7 Nov 2024 01:14:57 +0100") : use ringbuffer, clang-tidy fixes
- ([bc4289d](https://git.ide3.de/universumgames/mic-projekt/-/commit/bc4289d1f5da9c9d738c0064b9e8e6e5ce68025a)) Universumgames on [2024-11-07](## "Thu, 7 Nov 2024 01:13:23 +0100") : Merge branch 'main' into feature-pattern-record
- ([a589934](https://git.ide3.de/universumgames/mic-projekt/-/commit/a589934b623e6df17331466dfa71c8200d3757b0)) Universumgames on [2024-11-07](## "Thu, 7 Nov 2024 01:12:04 +0100") : clang tidy warnings fix, add ring buffer
- ([4ee3284](https://git.ide3.de/universumgames/mic-projekt/-/commit/4ee32843f754dd710362d57ee06e47837ea1c545)) Universumgames on [2024-11-06](## "Wed, 6 Nov 2024 10:28:53 +0100") : use pattern encoder
- ([9a449a9](https://git.ide3.de/universumgames/mic-projekt/-/commit/9a449a9fb719c0f943d320aab2b2a825804eb8b7)) Universumgames on [2024-11-06](## "Wed, 6 Nov 2024 10:28:33 +0100") : fix removed function
- ([f2abc81](https://git.ide3.de/universumgames/mic-projekt/-/commit/f2abc81f175aafa5feebb27add397ec25cf9f94c)) Universumgames on [2024-11-06](## "Wed, 6 Nov 2024 10:28:08 +0100") : test code to get best encoding
- ([164d8d9](https://git.ide3.de/universumgames/mic-projekt/-/commit/164d8d919e0c475301d8d3cb8e7afd5d2e25f218)) joarn002 on [2024-11-04](## "Mon, 4 Nov 2024 11:29:40 +0100") : Final_PCB
- ([b763fe7](https://git.ide3.de/universumgames/mic-projekt/-/commit/b763fe7c85d677d4c0f4ab9deaed440c78602f01)) Universumgames on [2024-11-04](## "Mon, 4 Nov 2024 10:54:28 +0100") : start implementing encoder
- ([419a9e4](https://git.ide3.de/universumgames/mic-projekt/-/commit/419a9e4fd7c1643755def9bc8519f0a75ead4ee9)) joarn002 on [2024-11-04](## "Mon, 4 Nov 2024 10:53:43 +0100") : update
- ([51852fc](https://git.ide3.de/universumgames/mic-projekt/-/commit/51852fc1c66c6a816714ba74f59618c33eaccdb1)) joarn002 on [2024-11-04](## "Mon, 4 Nov 2024 10:52:56 +0100") : update pcb
- ([6005cf1](https://git.ide3.de/universumgames/mic-projekt/-/commit/6005cf164df783f98859e31e1769f18476022e2d)) Universumgames on [2024-11-03](## "Sun, 3 Nov 2024 19:31:02 +0100") : Merge branch 'main' into feature-pattern-record
- ([c4d08db](https://git.ide3.de/universumgames/mic-projekt/-/commit/c4d08db1b22d5a6003379ebcf59df41f16dd6807)) Universumgames on [2024-11-03](## "Sun, 3 Nov 2024 19:28:43 +0100") : fix formatting in files
- ([dbd51ec](https://git.ide3.de/universumgames/mic-projekt/-/commit/dbd51ec270d8b9d6348b8530c54b01ecb3a73657)) Universumgames on [2024-11-03](## "Sun, 3 Nov 2024 19:28:26 +0100") : retest formatting
- ([c2b175e](https://git.ide3.de/universumgames/mic-projekt/-/commit/c2b175e0d891ed5a0c9d931703a36ec5ac0927ff)) Universumgames on [2024-11-03](## "Sun, 3 Nov 2024 19:25:15 +0100") : add automatic file formatting on commit
- ([9ff4b85](https://git.ide3.de/universumgames/mic-projekt/-/commit/9ff4b85c18811f13c920ed10843b651fa5acfaa8)) svehreschild on [2024-11-03](## "Sun, 3 Nov 2024 15:48:56 +0000") : Merge branch '14-schloss-status-led' into 'main'
- ([3349079](https://git.ide3.de/universumgames/mic-projekt/-/commit/3349079e03bdd2a7492a209bc51885b857d22e2a)) simonvehreschild on [2024-11-03](## "Sun, 3 Nov 2024 16:37:24 +0100") : Co-authored-by: Tom <programming@universegame.de>
- ([2100f28](https://git.ide3.de/universumgames/mic-projekt/-/commit/2100f28a90ef14fb986b44ffa62766a145e57458)) Universumgames on [2024-11-03](## "Sun, 3 Nov 2024 15:54:46 +0100") : update clang config
- ([ccde72c](https://git.ide3.de/universumgames/mic-projekt/-/commit/ccde72cd9da413228bc1257d3f428ab26a7a3648)) simonvehreschild on [2024-11-03](## "Sun, 3 Nov 2024 15:31:15 +0100") : update
- ([61dbbf1](https://git.ide3.de/universumgames/mic-projekt/-/commit/61dbbf17137a23075a859e66eebe9ea8ba73c693)) Universumgames on [2024-11-03](## "Sun, 3 Nov 2024 14:59:19 +0100") : fix analog read
- ([a6eaa9a](https://git.ide3.de/universumgames/mic-projekt/-/commit/a6eaa9a864a7dba3c9d0013e3ed7c0483dc71efd)) simonvehreschild on [2024-11-02](## "Sat, 2 Nov 2024 13:20:55 +0100") : update
- ([a50cd6d](https://git.ide3.de/universumgames/mic-projekt/-/commit/a50cd6da9f860241eb1349d03e1052d451d5cea7)) simonvehreschild on [2024-11-02](## "Sat, 2 Nov 2024 04:38:29 +0100") : update, Anpassungen der Hinweise
- ([00924a8](https://git.ide3.de/universumgames/mic-projekt/-/commit/00924a8704ae5cd09cf198b1d17a15bbe0356f54)) Universumgames on [2024-11-01](## "Fri, 1 Nov 2024 23:57:17 +0100") : fix platformio.ini corrupted on merge
- ([2ecf887](https://git.ide3.de/universumgames/mic-projekt/-/commit/2ecf887aaa9710332acb3530c4b55a19d87611c5)) Universumgames on [2024-11-01](## "Fri, 1 Nov 2024 23:49:24 +0100") : Merge branch 'main' into feature-pattern-record
- ([2607671](https://git.ide3.de/universumgames/mic-projekt/-/commit/2607671f6e2343d5591d79dc5ba285117a36883a)) Universumgames on [2024-11-01](## "Fri, 1 Nov 2024 23:44:46 +0100") : Merge branch 'main' into 14-schloss-status-led
- ([daf5ba2](https://git.ide3.de/universumgames/mic-projekt/-/commit/daf5ba2229b1667af7e6c672d46a8f32f7e46c08)) Universumgames on [2024-11-01](## "Fri, 1 Nov 2024 23:43:02 +0100") : add formatter and githooks
- ([6e950ab](https://git.ide3.de/universumgames/mic-projekt/-/commit/6e950ab9c8ef0dbd14ff24605bc61ffab102c709)) simonvehreschild on [2024-11-01](## "Fri, 1 Nov 2024 19:14:36 +0100") : test
- ([d0d8d69](https://git.ide3.de/universumgames/mic-projekt/-/commit/d0d8d69ae49e5292d2fce60f60eb0810dabd09cf)) simonvehreschild on [2024-11-01](## "Fri, 1 Nov 2024 19:09:50 +0100") : pipeline fail korrektur
- ([5ed0b4e](https://git.ide3.de/universumgames/mic-projekt/-/commit/5ed0b4eb34a219570c70926f08d6fb6d8f2b2727)) simonvehreschild on [2024-11-01](## "Fri, 1 Nov 2024 18:57:02 +0100") : fertig
- ([7bc6055](https://git.ide3.de/universumgames/mic-projekt/-/commit/7bc6055a7bb1f8185a3e6204f7e8f961a2c30220)) simonvehreschild on [2024-11-01](## "Fri, 1 Nov 2024 17:38:40 +0100") : update
- ([e146c6b](https://git.ide3.de/universumgames/mic-projekt/-/commit/e146c6b7c45ca60ab892abeb8a73d43337219fde)) simonvehreschild on [2024-11-01](## "Fri, 1 Nov 2024 15:58:34 +0100") : lib extern led first attempt
- ([a4fc5a5](https://git.ide3.de/universumgames/mic-projekt/-/commit/a4fc5a5ad97abc72336d1a9df37ee4f4b072dc3f)) simonvehreschild on [2024-11-01](## "Fri, 1 Nov 2024 15:33:58 +0100") : update
- ([8778e27](https://git.ide3.de/universumgames/mic-projekt/-/commit/8778e270e1622eda6f5525a007524e7787e29aac)) Universumgames on [2024-10-30](## "Wed, 30 Oct 2024 19:58:27 +0100") : fix int types
- ([ffcadd8](https://git.ide3.de/universumgames/mic-projekt/-/commit/ffcadd807b9406e338e93b46c0bf086d0f8d202c)) Universumgames on [2024-10-30](## "Wed, 30 Oct 2024 13:13:14 +0100") : update comments, add code check to cicd
- ([fa70355](https://git.ide3.de/universumgames/mic-projekt/-/commit/fa703552eb888062bc76d002edbec24ce6b9c385)) Universumgames on [2024-10-30](## "Wed, 30 Oct 2024 11:30:40 +0100") : cleanup
- ([dd53bef](https://git.ide3.de/universumgames/mic-projekt/-/commit/dd53befe04ccbec1981f64e2506a5d718419672d)) Tom Arlt on [2024-10-30](## "Wed, 30 Oct 2024 10:07:01 +0000") : Merge branch 'feature-store-pattern' into 'main'
- ([4bd1f3e](https://git.ide3.de/universumgames/mic-projekt/-/commit/4bd1f3e62d65ac44d4c2e5c98c434fea8d708006)) Tom Arlt on [2024-10-30](## "Wed, 30 Oct 2024 10:07:01 +0000") : Resolve "Muster einspeichern"
- ([dc37374](https://git.ide3.de/universumgames/mic-projekt/-/commit/dc37374ca8c5570d88df7574b7e294777172d14f)) Universumgames on [2024-10-30](## "Wed, 30 Oct 2024 09:49:38 +0100") : fix ci stage test
- ([2cd316d](https://git.ide3.de/universumgames/mic-projekt/-/commit/2cd316d72530d4654f862534f7b7e3f19d1522b1)) Universumgames on [2024-10-30](## "Wed, 30 Oct 2024 09:42:47 +0100") : use updated gitlab ci file
- ([945c498](https://git.ide3.de/universumgames/mic-projekt/-/commit/945c498280d2353e0c319cc51df67e50125c467f)) Universumgames on [2024-10-30](## "Wed, 30 Oct 2024 09:38:59 +0100") : should work now
- ([43ef9bd](https://git.ide3.de/universumgames/mic-projekt/-/commit/43ef9bd6d1c6d4a33e37ad1f22127a73aca7d7ec)) Universumgames on [2024-10-30](## "Wed, 30 Oct 2024 09:36:53 +0100") : another ci test
- ([a2e5094](https://git.ide3.de/universumgames/mic-projekt/-/commit/a2e5094e45b55036b2f4c9de8d4e5239bed83a63)) Universumgames on [2024-10-30](## "Wed, 30 Oct 2024 09:34:49 +0100") : another ci cache test
- ([d36dffc](https://git.ide3.de/universumgames/mic-projekt/-/commit/d36dffc92c73b4b02bd97d8c3a8f627df74df0d4)) Universumgames on [2024-10-30](## "Wed, 30 Oct 2024 09:16:16 +0100") : fix path
- ([6d59ca3](https://git.ide3.de/universumgames/mic-projekt/-/commit/6d59ca3aceb82952a126eed15defc7b1dd70e893)) Universumgames on [2024-10-30](## "Wed, 30 Oct 2024 09:14:25 +0100") : test cache with symlinks
- ([e3b01d3](https://git.ide3.de/universumgames/mic-projekt/-/commit/e3b01d389664e3c150528aaece48c824a1de5555)) Universumgames on [2024-10-29](## "Tue, 29 Oct 2024 22:47:17 +0100") : fix compile
- ([fc36aab](https://git.ide3.de/universumgames/mic-projekt/-/commit/fc36aabba44ce30534012e6a24c722836f1d0df8)) Universumgames on [2024-10-29](## "Tue, 29 Oct 2024 21:03:56 +0100") : moving files, starting to implement pattern recorder
- ([d7785b7](https://git.ide3.de/universumgames/mic-projekt/-/commit/d7785b7dd5994f8551a7396773e7f351450ff919)) Universumgames on [2024-10-29](## "Tue, 29 Oct 2024 13:58:23 +0100") : Merge remote-tracking branch 'origin/main'
- ([7be21d4](https://git.ide3.de/universumgames/mic-projekt/-/commit/7be21d4e2245af8b4cdba51097fd34153e59734c)) UniversumGames on [2024-10-29](## "Tue, 29 Oct 2024 13:54:48 +0100") : another fix
- ([24728e1](https://git.ide3.de/universumgames/mic-projekt/-/commit/24728e157c9fc1603c9dcf2f854bafcbcfcb24ad)) UniversumGames on [2024-10-29](## "Tue, 29 Oct 2024 13:49:50 +0100") : fix cicd
- ([de38159](https://git.ide3.de/universumgames/mic-projekt/-/commit/de3815985d28654587569ec172b0fa9944143c4e)) UniversumGames on [2024-10-29](## "Tue, 29 Oct 2024 13:42:59 +0100") : try fixing cicd
- ([ee3e5b2](https://git.ide3.de/universumgames/mic-projekt/-/commit/ee3e5b2bef9e0df936cd01a99d0161af37d24542)) UniversumGames on [2024-10-29](## "Tue, 29 Oct 2024 13:25:17 +0100") : from yaml
- ([00aea7f](https://git.ide3.de/universumgames/mic-projekt/-/commit/00aea7f229a3498a326e2263dc76d61438c4e2d2)) UniversumGames on [2024-10-29](## "Tue, 29 Oct 2024 13:24:52 +0100") : adjust cicd to use cache
- ([2c8a243](https://git.ide3.de/universumgames/mic-projekt/-/commit/2c8a243f990b1637d008bab29f6f4dbafea027a4)) UniversumGames on [2024-10-29](## "Tue, 29 Oct 2024 13:22:34 +0100") : retest
- ([485a129](https://git.ide3.de/universumgames/mic-projekt/-/commit/485a129fa4c8073224e79dbdc357bda44a40c33f)) UniversumGames on [2024-10-29](## "Tue, 29 Oct 2024 13:19:55 +0100") : cicd test
- ([a4e82c7](https://git.ide3.de/universumgames/mic-projekt/-/commit/a4e82c790279a34f734f6c1b351dcf0a70a957dd)) UniversumGames on [2024-10-29](## "Tue, 29 Oct 2024 12:24:41 +0100") : test cicd
- ([b7431e4](https://git.ide3.de/universumgames/mic-projekt/-/commit/b7431e43653f1dcf17d72b698ef759b40d2dc4cc)) Universumgames on [2024-10-29](## "Tue, 29 Oct 2024 12:22:15 +0100") : Merge remote-tracking branch 'origin/main' into feature-pattern-record
- ([ac2a4ec](https://git.ide3.de/universumgames/mic-projekt/-/commit/ac2a4ec3c0a224656faef4f5d5ac05a9e9f71ee8)) UniversumGames on [2024-10-29](## "Tue, 29 Oct 2024 12:21:58 +0100") : fix speedup of cicd
- ([e742a33](https://git.ide3.de/universumgames/mic-projekt/-/commit/e742a33d560dc2bbc14a89e88f8ece9e99eb6635)) Universumgames on [2024-10-29](## "Tue, 29 Oct 2024 12:15:57 +0100") : Merge remote-tracking branch 'origin/main' into feature-pattern-record
- ([1f9ad3c](https://git.ide3.de/universumgames/mic-projekt/-/commit/1f9ad3cbf030e872e32deda489af642f0d378169)) UniversumGames on [2024-10-29](## "Tue, 29 Oct 2024 12:15:33 +0100") : speed up cicd
- ([7f8b210](https://git.ide3.de/universumgames/mic-projekt/-/commit/7f8b210ba65898ce8c245680712f9e2109ae0aed)) UniversumGames on [2024-10-29](## "Tue, 29 Oct 2024 12:06:38 +0100") : adding rsicv toolchain installation
- ([0831512](https://git.ide3.de/universumgames/mic-projekt/-/commit/083151238546144b0964aacd84a49d337d72f03e)) Universumgames on [2024-10-29](## "Tue, 29 Oct 2024 11:52:07 +0100") : not using x64 assembly
- ([b5ca4fd](https://git.ide3.de/universumgames/mic-projekt/-/commit/b5ca4fd3368409426fa459a7ecf2fa8b9d53a5f4)) Universumgames on [2024-10-28](## "Mon, 28 Oct 2024 23:44:40 +0100") : add knock recordings
- ([3b618e5](https://git.ide3.de/universumgames/mic-projekt/-/commit/3b618e58d6d5b87967b068e5f412e1804466aa40)) Universumgames on [2024-10-28](## "Mon, 28 Oct 2024 23:39:51 +0100") : retest native assembly
- ([ec77e4e](https://git.ide3.de/universumgames/mic-projekt/-/commit/ec77e4e1b939f981866cedb86181e5fec81f3ca5)) Universumgames on [2024-10-28](## "Mon, 28 Oct 2024 23:15:14 +0100") : fix multiplatform build
- ([314d4e2](https://git.ide3.de/universumgames/mic-projekt/-/commit/314d4e25a128ff5de86b8ab6dbf2653b3820f6af)) Universumgames on [2024-10-28](## "Mon, 28 Oct 2024 03:03:56 +0100") : fix platform specific assembler
- ([235c42e](https://git.ide3.de/universumgames/mic-projekt/-/commit/235c42e0c1b89cd38537d36eb390d14e20a8d77f)) Universumgames on [2024-10-27](## "Sun, 27 Oct 2024 13:49:44 +0100") : fix comments in assembly
- ([a28b28e](https://git.ide3.de/universumgames/mic-projekt/-/commit/a28b28ec6ac6583b12c252354fc7a7bee2d967f4)) Universumgames on [2024-10-27](## "Sun, 27 Oct 2024 13:45:48 +0100") : fix esp build
- ([09977dc](https://git.ide3.de/universumgames/mic-projekt/-/commit/09977dc38c58f49f00b33b102c4277e60d6da59c)) Universumgames on [2024-10-27](## "Sun, 27 Oct 2024 13:13:56 +0100") : in assembly differentiate between arm and x64
- ([026e826](https://git.ide3.de/universumgames/mic-projekt/-/commit/026e826a60b8cae5fe4e8c6462499d59d5e5094c)) Universumgames on [2024-10-27](## "Sun, 27 Oct 2024 12:56:25 +0100") : implement max function as assembler, add support for platform specific assembler
- ([c929c0e](https://git.ide3.de/universumgames/mic-projekt/-/commit/c929c0e14c75e2a1ddc649861dcb76e5f811ed1d)) Universumgames on [2024-10-27](## "Sun, 27 Oct 2024 12:54:45 +0100") : add pattern storage test
- ([1f88b78](https://git.ide3.de/universumgames/mic-projekt/-/commit/1f88b78afa8c512e210808041beef88d97f06f45)) Universumgames on [2024-10-27](## "Sun, 27 Oct 2024 12:54:34 +0100") : refactoring
- ([de7afdf](https://git.ide3.de/universumgames/mic-projekt/-/commit/de7afdfe1ad17b80edae274f3952839cb257f6e6)) Universumgames on [2024-10-27](## "Sun, 27 Oct 2024 02:04:06 +0100") : fix pattern storage driver and write tests
- ([7f8501e](https://git.ide3.de/universumgames/mic-projekt/-/commit/7f8501e265e99db3028c638b39362339f2b2ebe7)) Universumgames on [2024-10-27](## "Sun, 27 Oct 2024 00:59:09 +0200") : adding platform specific definitions and compilations
- ([894c0cb](https://git.ide3.de/universumgames/mic-projekt/-/commit/894c0cbb2b6631eff246f020c0318bfd46a43909)) Universumgames on [2024-10-27](## "Sun, 27 Oct 2024 00:11:40 +0200") : restructure pattern struct to add struct versioning
- ([b109d47](https://git.ide3.de/universumgames/mic-projekt/-/commit/b109d472d6a4c22f56df81c0d566161eae314418)) Universumgames on [2024-10-26](## "Sat, 26 Oct 2024 15:32:55 +0200") : Merge branch 'main' into feature-pattern-record
- ([e5a1306](https://git.ide3.de/universumgames/mic-projekt/-/commit/e5a13068017ba49fcf5e0b999c10f82aa809652c)) Tom Arlt on [2024-10-26](## "Sat, 26 Oct 2024 13:31:45 +0000") : Merge branch 'feature-pattern-storage' into 'main'
- ([4dde21a](https://git.ide3.de/universumgames/mic-projekt/-/commit/4dde21a52beb9b5a7770a39749f084b33104a274)) Universumgames on [2024-10-26](## "Sat, 26 Oct 2024 15:29:19 +0200") : implement pattern storage
- ([97b44b7](https://git.ide3.de/universumgames/mic-projekt/-/commit/97b44b79d76f80a0f1819de9f0662498a069ed92)) Universumgames on [2024-10-25](## "Fri, 25 Oct 2024 23:00:51 +0200") : finish pattern storage
- ([8eabfb1](https://git.ide3.de/universumgames/mic-projekt/-/commit/8eabfb1b35980388cf32b6401551eb18e571e568)) Universumgames on [2024-10-25](## "Fri, 25 Oct 2024 12:49:39 +0200") : fix include
- ([59044c1](https://git.ide3.de/universumgames/mic-projekt/-/commit/59044c18718d009ee089bb71dc0ceb2a1f8d4434)) Universumgames on [2024-10-25](## "Fri, 25 Oct 2024 12:48:43 +0200") : update changelog
- ([06bbbba](https://git.ide3.de/universumgames/mic-projekt/-/commit/06bbbba53ecb8b6f950baf375ff01319439e6bee)) Universumgames on [2024-10-25](## "Fri, 25 Oct 2024 12:48:34 +0200") : fix include
- ([1635f4a](https://git.ide3.de/universumgames/mic-projekt/-/commit/1635f4a07e10f5a0a8220045a11488f2d4c2040c)) Universumgames on [2024-10-25](## "Fri, 25 Oct 2024 12:12:35 +0200") : fix basicdefs
- ([6ffc164](https://git.ide3.de/universumgames/mic-projekt/-/commit/6ffc164e5de5cc495d6b595688ddeb12c551d27b)) Universumgames on [2024-10-25](## "Fri, 25 Oct 2024 12:12:14 +0200") : fix basicdefs
- ([9e22f77](https://git.ide3.de/universumgames/mic-projekt/-/commit/9e22f77d7b7cdd37d39ad23794bad3147b876814)) Universumgames on [2024-10-25](## "Fri, 25 Oct 2024 12:10:50 +0200") : add first code of conduct and contributing
- ([d798a4a](https://git.ide3.de/universumgames/mic-projekt/-/commit/d798a4af4c9fa6acb73b45cea66d5170bc04e185)) Universumgames on [2024-10-25](## "Fri, 25 Oct 2024 12:04:31 +0200") : add changelog
- ([5f03043](https://git.ide3.de/universumgames/mic-projekt/-/commit/5f030430667ad9b941de6ba988534add2ee7017c)) Universumgames on [2024-10-25](## "Fri, 25 Oct 2024 12:03:50 +0200") : init pattern storage
- ([7dc0c34](https://git.ide3.de/universumgames/mic-projekt/-/commit/7dc0c34e57f97576caef365538b8afae46b79a7d)) Universumgames on [2024-10-25](## "Fri, 25 Oct 2024 00:13:26 +0200") : add pattern storage
- ([132c47c](https://git.ide3.de/universumgames/mic-projekt/-/commit/132c47c3979a3d52794d55ff7d74b256321c64d0)) Universumgames on [2024-10-25](## "Fri, 25 Oct 2024 00:12:54 +0200") : Merge branch 'main' into feature-pattern-record
- ([681f5c8](https://git.ide3.de/universumgames/mic-projekt/-/commit/681f5c80a65015f91776209bc7ceaeb750fcd4a0)) Universumgames on [2024-10-25](## "Fri, 25 Oct 2024 00:12:06 +0200") : update cpp header pragma
- ([8069149](https://git.ide3.de/universumgames/mic-projekt/-/commit/806914973e5436056c38041b2a08a112e0b5ce55)) Universumgames on [2024-10-24](## "Thu, 24 Oct 2024 19:35:29 +0200") : update changelog generator
- ([f1af63c](https://git.ide3.de/universumgames/mic-projekt/-/commit/f1af63c1447796527ba159470a3f0eaf79fbc33a)) Universumgames on [2024-10-24](## "Thu, 24 Oct 2024 19:22:27 +0200") : update gitignore
- ([dd544ed](https://git.ide3.de/universumgames/mic-projekt/-/commit/dd544ed2875198445b253a32b75fc0eacaca5be9)) Universumgames on [2024-10-24](## "Thu, 24 Oct 2024 19:22:13 +0200") : Merge branch 'main' into feature-pattern-record
- ([a3e37bc](https://git.ide3.de/universumgames/mic-projekt/-/commit/a3e37bc710f102bb57bba86d81e39aaf9472fc3f)) Tom Arlt on [2024-10-24](## "Thu, 24 Oct 2024 17:20:48 +0000") : Merge branch 'test-feature-led-driver' into 'main'
- ([f6febe0](https://git.ide3.de/universumgames/mic-projekt/-/commit/f6febe07e0d8dc620bdb8cf04ff344ce22ad9647)) Universumgames on [2024-10-24](## "Thu, 24 Oct 2024 19:12:42 +0200") : updating basic def header
- ([15205e7](https://git.ide3.de/universumgames/mic-projekt/-/commit/15205e7742cd7e24301b7549201040898f748559)) Universumgames on [2024-10-24](## "Thu, 24 Oct 2024 19:11:42 +0200") : simplify and remove old code
- ([e5c8565](https://git.ide3.de/universumgames/mic-projekt/-/commit/e5c85659cb51875c8b56ece574aa5ca9dd4e1934)) Universumgames on [2024-10-24](## "Thu, 24 Oct 2024 18:59:41 +0200") : simplifying rmt config
- ([32f4616](https://git.ide3.de/universumgames/mic-projekt/-/commit/32f4616ad4bc74d97320bacf542a9991aea52fe1)) Universumgames on [2024-10-24](## "Thu, 24 Oct 2024 18:08:43 +0200") : trying out i2s lib (not working)
- ([004213b](https://git.ide3.de/universumgames/mic-projekt/-/commit/004213ba00672219b7751ead2c29c8951be74566)) Universumgames on [2024-10-23](## "Wed, 23 Oct 2024 23:44:49 +0200") : trying out i2s (not working at all)
- ([6cbc640](https://git.ide3.de/universumgames/mic-projekt/-/commit/6cbc6406dc55131f6c01f85dcafd58ff8dd11dd5)) Universumgames on [2024-10-22](## "Tue, 22 Oct 2024 12:34:25 +0200") : add led spi explanation image
- ([9b0c969](https://git.ide3.de/universumgames/mic-projekt/-/commit/9b0c96980fb5496ad1ce06975585aa8afa5909ad)) Universumgames on [2024-10-22](## "Tue, 22 Oct 2024 12:31:13 +0200") : try fixing LED driver with spi control, not usable because overwriting storage bus
- ([d40191b](https://git.ide3.de/universumgames/mic-projekt/-/commit/d40191b7948eae47b1e13e3a23f74fa50e8cff13)) Universumgames on [2024-10-22](## "Tue, 22 Oct 2024 11:04:10 +0200") : implement basic analog read
- ([2cf7b20](https://git.ide3.de/universumgames/mic-projekt/-/commit/2cf7b20c16da66ea31dbc9a2b5b0c781ee7cdf36)) Universumgames on [2024-10-22](## "Tue, 22 Oct 2024 11:03:36 +0200") : try fixing led
- ([5d9cf31](https://git.ide3.de/universumgames/mic-projekt/-/commit/5d9cf31d983caa6cee7c2a0ee5b3bd7cbfe59d54)) Universumgames on [2024-10-22](## "Tue, 22 Oct 2024 00:50:15 +0200") : preparing further implementation, adding analog read test task
- ([da5bcc9](https://git.ide3.de/universumgames/mic-projekt/-/commit/da5bcc900ea7cbd5c339d6d0e2ceaba8e565a754)) Universumgames on [2024-10-22](## "Tue, 22 Oct 2024 00:12:48 +0200") : add additional expect for storage test
- ([a9dfdb8](https://git.ide3.de/universumgames/mic-projekt/-/commit/a9dfdb8f036778020509e1057dc55139e8d311c5)) Universumgames on [2024-10-22](## "Tue, 22 Oct 2024 00:12:25 +0200") : add changelog
- ([a2f756e](https://git.ide3.de/universumgames/mic-projekt/-/commit/a2f756e8ea3a0d030a2c07eea35ae77967bce39c)) Universumgames on [2024-10-21](## "Mon, 21 Oct 2024 22:00:41 +0200") : prepare analog read
- ([3347105](https://git.ide3.de/universumgames/mic-projekt/-/commit/3347105564a00b158b8be1b29b7c05a8a67f64b7)) Tom Arlt on [2024-10-20](## "Sun, 20 Oct 2024 21:45:37 +0000") : Merge branch 'feature-storage-driver' into 'main'
- ([b021204](https://git.ide3.de/universumgames/mic-projekt/-/commit/b021204337b89a51d887ececc05a7f0d4d3b83aa)) Universumgames on [2024-10-20](## "Sun, 20 Oct 2024 23:40:14 +0200") : fix main
- ([3bc64c8](https://git.ide3.de/universumgames/mic-projekt/-/commit/3bc64c89b3d3f7415abf177dfc4c9cc62f999005)) Universumgames on [2024-10-20](## "Sun, 20 Oct 2024 23:37:06 +0200") : add test templates
- ([0656771](https://git.ide3.de/universumgames/mic-projekt/-/commit/06567714da6672b19d834d9ed7de2253f2a8b230)) Universumgames on [2024-10-20](## "Sun, 20 Oct 2024 23:35:08 +0200") : add storage test
- ([ee5371d](https://git.ide3.de/universumgames/mic-projekt/-/commit/ee5371dc20fa4852368682b2183f156e5275715a)) Universumgames on [2024-10-20](## "Sun, 20 Oct 2024 23:34:59 +0200") : fix bug in lsDir
- ([ba72fce](https://git.ide3.de/universumgames/mic-projekt/-/commit/ba72fceeaadf249c489b2bcead6d9fad45a47333)) Universumgames on [2024-10-20](## "Sun, 20 Oct 2024 23:34:49 +0200") : add error handling to mounting
- ([ecd584e](https://git.ide3.de/universumgames/mic-projekt/-/commit/ecd584e235d0e1030e7abed2c5cae8aa28e8e9f5)) Universumgames on [2024-10-20](## "Sun, 20 Oct 2024 23:16:26 +0200") : add fileExists and add comments for common file operations
- ([ec74f72](https://git.ide3.de/universumgames/mic-projekt/-/commit/ec74f72fc1fc5ac5c9a749ebb7163117411b6f6a)) Universumgames on [2024-10-20](## "Sun, 20 Oct 2024 23:14:06 +0200") : add basic definitions
- ([e56aefd](https://git.ide3.de/universumgames/mic-projekt/-/commit/e56aefd687f7a62a6d9328073ce239a790b7294c)) Universumgames on [2024-10-18](## "Fri, 18 Oct 2024 16:04:37 +0200") : fixed unit tests
- ([f8d24d4](https://git.ide3.de/universumgames/mic-projekt/-/commit/f8d24d4df676940a955bbd424de9573f1de3a179)) Universumgames on [2024-10-18](## "Fri, 18 Oct 2024 15:35:51 +0200") : add testing framework and fix string methods
- ([457fd4a](https://git.ide3.de/universumgames/mic-projekt/-/commit/457fd4af31335f8a9289a30ea0533181893ca748)) Universumgames on [2024-10-18](## "Fri, 18 Oct 2024 01:48:14 +0200") : fix cicd try 7
- ([ac79808](https://git.ide3.de/universumgames/mic-projekt/-/commit/ac7980855fe3ffb8f1b7984242f7c668c7a7d3b7)) Universumgames on [2024-10-18](## "Fri, 18 Oct 2024 01:11:37 +0200") : cicd try fix 5
- ([e839c07](https://git.ide3.de/universumgames/mic-projekt/-/commit/e839c0785cf5aadc5e918dcf90fefb2658c7abe1)) Universumgames on [2024-10-18](## "Fri, 18 Oct 2024 01:10:04 +0200") : try cicd fix 4
- ([e870f71](https://git.ide3.de/universumgames/mic-projekt/-/commit/e870f713ece0c5c795dba991c3e7429869e4f8a4)) Universumgames on [2024-10-17](## "Thu, 17 Oct 2024 20:54:17 +0200") : try ci cd 3
- ([048a51f](https://git.ide3.de/universumgames/mic-projekt/-/commit/048a51fe2584423fd69703f684e8034b8442c83e)) simonvehreschild on [2024-10-17](## "Thu, 17 Oct 2024 20:46:50 +0200") : update Sprintplan
- ([5c68ad5](https://git.ide3.de/universumgames/mic-projekt/-/commit/5c68ad5810bdfcea6c67235f56becbd4f9969ca5)) simonvehreschild on [2024-10-17](## "Thu, 17 Oct 2024 20:42:28 +0200") : update-README-und-Text-Präsentation
- ([e0d1d45](https://git.ide3.de/universumgames/mic-projekt/-/commit/e0d1d453daf3894fcc89e1c09081cd5b0461c755)) Universumgames on [2024-10-17](## "Thu, 17 Oct 2024 20:37:56 +0200") : try fix 2
- ([2012cc5](https://git.ide3.de/universumgames/mic-projekt/-/commit/2012cc51c8e88ab6b398a7fe18599f15be018a41)) Universumgames on [2024-10-17](## "Thu, 17 Oct 2024 20:35:42 +0200") : try fixing ci/cd
- ([d112d12](https://git.ide3.de/universumgames/mic-projekt/-/commit/d112d129a6a0e6a70dda93f940122245a0d5a7b0)) Universumgames on [2024-10-17](## "Thu, 17 Oct 2024 20:29:09 +0200") : test ci/cd
- ([e873cde](https://git.ide3.de/universumgames/mic-projekt/-/commit/e873cdede895a0a247516fecf7bd3dbece508163)) Universumgames on [2024-10-17](## "Thu, 17 Oct 2024 20:03:52 +0200") : update built type
- ([30b06b3](https://git.ide3.de/universumgames/mic-projekt/-/commit/30b06b3cc324bf7cb75c6232b23082b3553ba7b9)) Universumgames on [2024-10-16](## "Wed, 16 Oct 2024 20:19:26 +0200") : FInish documentation for Sprint 1 with Simon and Jovan
- ([2da1056](https://git.ide3.de/universumgames/mic-projekt/-/commit/2da1056b0940b3a1bd7b5c71841e4144947efacd)) Universumgames on [2024-10-16](## "Wed, 16 Oct 2024 19:24:06 +0200") : preparing documentation
- ([76d86c3](https://git.ide3.de/universumgames/mic-projekt/-/commit/76d86c32dc204eb8654a452e381dbff98d088878)) Universumgames on [2024-10-16](## "Wed, 16 Oct 2024 19:12:10 +0200") : Co-authored-by: Simon Vehreschild <svehreschild@users.noreply.github.com>
- ([025235c](https://git.ide3.de/universumgames/mic-projekt/-/commit/025235ca33e95b409395c0584428b04cf93782cf)) Universumgames on [2024-10-16](## "Wed, 16 Oct 2024 18:25:32 +0200") : add first documentation file
- ([3cf6cb6](https://git.ide3.de/universumgames/mic-projekt/-/commit/3cf6cb6fad2370768018fd4502e336cfd64e8143)) Universumgames on [2024-10-16](## "Wed, 16 Oct 2024 18:21:31 +0200") : update assets and schematic
- ([77cf8b4](https://git.ide3.de/universumgames/mic-projekt/-/commit/77cf8b42c1bf098ea796ebeebdb0d2b29d7a6035)) Tom Arlt on [2024-10-15](## "Tue, 15 Oct 2024 18:51:22 +0000") : Merge branch 'Update_Circuit_switch' into 'main'
- ([e729de0](https://git.ide3.de/universumgames/mic-projekt/-/commit/e729de036a8aee4f1dd808a89e3b388019dfb9c7)) simonvehreschild on [2024-10-15](## "Tue, 15 Oct 2024 20:15:50 +0200") : update
- ([4215d72](https://git.ide3.de/universumgames/mic-projekt/-/commit/4215d729f1fd6acc313ca035f3c366f18115d16b)) simonvehreschild on [2024-10-15](## "Tue, 15 Oct 2024 20:03:34 +0200") : update
- ([ecb114d](https://git.ide3.de/universumgames/mic-projekt/-/commit/ecb114d629c8d3623d8dff112341fdfe1eea8867)) Tom Arlt on [2024-10-14](## "Mon, 14 Oct 2024 22:47:51 +0000") : Merge branch 'update_pcb' into 'main'
- ([202fdf4](https://git.ide3.de/universumgames/mic-projekt/-/commit/202fdf4f46c797d9994fc980b3b99e00de1a8e90)) simonvehreschild on [2024-10-14](## "Mon, 14 Oct 2024 21:43:51 +0200") : update pcd mit Notöffnung
- ([98f3930](https://git.ide3.de/universumgames/mic-projekt/-/commit/98f3930d8624877f5fd2022d00bc222ccb6a1b66)) Universumgames on [2024-10-14](## "Mon, 14 Oct 2024 20:19:25 +0200") : add pcb
- ([d7d4276](https://git.ide3.de/universumgames/mic-projekt/-/commit/d7d4276ef6406cb32793c97e63a5690d8e5ad19d)) Universumgames on [2024-10-14](## "Mon, 14 Oct 2024 11:34:54 +0200") : fix library includes
- ([71899c0](https://git.ide3.de/universumgames/mic-projekt/-/commit/71899c0432226f1e7f66d8dabf1beded1aa19b63)) Universumgames on [2024-10-14](## "Mon, 14 Oct 2024 11:30:42 +0200") : remove all vs code files
- ([57d8b40](https://git.ide3.de/universumgames/mic-projekt/-/commit/57d8b401be7b678ea7fba60cd930a789026fa755)) Tom Arlt on [2024-10-14](## "Mon, 14 Oct 2024 09:29:37 +0000") : Merge branch 'feature-storage-driver' into 'main'
- ([2bcffe8](https://git.ide3.de/universumgames/mic-projekt/-/commit/2bcffe8536bf1138b33073c55c8742c8ba23f7b5)) Universumgames on [2024-10-14](## "Mon, 14 Oct 2024 11:29:09 +0200") : Merge branch 'main' of https://git.ide3.de/universumgames/mic-projekt into feature-storage-driver
- ([b65cb25](https://git.ide3.de/universumgames/mic-projekt/-/commit/b65cb250cf85f31960e4ee8c0ce654c384d81ec5)) Tom Arlt on [2024-10-14](## "Mon, 14 Oct 2024 09:25:12 +0000") : Merge branch 'feature-lock' into 'main'
- ([b75e08a](https://git.ide3.de/universumgames/mic-projekt/-/commit/b75e08a81a3fee8292a5e0b11c4c2dca488508fc)) Tom Arlt on [2024-10-14](## "Mon, 14 Oct 2024 09:21:07 +0000") : Merge branch 'main' into 'feature-lock'
- ([a84312c](https://git.ide3.de/universumgames/mic-projekt/-/commit/a84312c4da8707c00b0683ed6b1b0e1984a54f3a)) simonvehreschild on [2024-10-14](## "Mon, 14 Oct 2024 11:16:42 +0200") : finish (revision Tom, Jovan)
- ([025a4e7](https://git.ide3.de/universumgames/mic-projekt/-/commit/025a4e7b53c834d32a2776f4256b2e38721f0113)) Universumgames on [2024-10-14](## "Mon, 14 Oct 2024 10:44:04 +0200") : add pinout list
- ([845f380](https://git.ide3.de/universumgames/mic-projekt/-/commit/845f380ac1237899d801150cf0725e33cf4b1484)) Universumgames on [2024-10-14](## "Mon, 14 Oct 2024 00:05:18 +0200") : finish basic storage driver
- ([db07620](https://git.ide3.de/universumgames/mic-projekt/-/commit/db07620dab579bad0ce28adeddd5320a6091ee05)) Universumgames on [2024-10-14](## "Mon, 14 Oct 2024 00:05:00 +0200") : add new pinout diagram, fix dependencies
- ([566057b](https://git.ide3.de/universumgames/mic-projekt/-/commit/566057b6b86188b38da4b2ed1f07a8b53f132c38)) Universumgames on [2024-10-14](## "Mon, 14 Oct 2024 00:04:44 +0200") : fixed implementation in linked list
- ([3debd23](https://git.ide3.de/universumgames/mic-projekt/-/commit/3debd2319ec15b7f943784decf6f021d69011d93)) simonvehreschild on [2024-10-13](## "Sun, 13 Oct 2024 19:39:53 +0200") : lock_open fertig
- ([6a1f910](https://git.ide3.de/universumgames/mic-projekt/-/commit/6a1f9107cfb7d615c858905367b4ada0af238768)) simonvehreschild on [2024-10-13](## "Sun, 13 Oct 2024 16:22:07 +0200") : 
- ([c1c8dfd](https://git.ide3.de/universumgames/mic-projekt/-/commit/c1c8dfd69f9740e4b61e8827f04e5bd964ee4385)) simonvehreschild on [2024-10-12](## "Sat, 12 Oct 2024 18:59:57 +0200") : test
- ([3c6289f](https://git.ide3.de/universumgames/mic-projekt/-/commit/3c6289f1f95bcfdd38cbc256f7718c71d09f1462)) Universumgames on [2024-10-11](## "Fri, 11 Oct 2024 19:59:55 +0200") : update gitignore
- ([128a82e](https://git.ide3.de/universumgames/mic-projekt/-/commit/128a82e10410dca8237605098809bfc1211e9a82)) Universumgames on [2024-10-11](## "Fri, 11 Oct 2024 19:59:05 +0200") : Merge branch 'main' of https://git.ide3.de/universumgames/mic-projekt into feature-storage-driver
- ([db45b7b](https://git.ide3.de/universumgames/mic-projekt/-/commit/db45b7bb4262ed5a6db781f00ec6c44ce826a8db)) Universumgames on [2024-10-11](## "Fri, 11 Oct 2024 19:57:08 +0200") : add linked list
- ([f95e07d](https://git.ide3.de/universumgames/mic-projekt/-/commit/f95e07d94de17d950d6a0b4d91521b98a5b35f35)) Universumgames on [2024-10-11](## "Fri, 11 Oct 2024 19:50:11 +0200") : implement storage driver first part
- ([dcab778](https://git.ide3.de/universumgames/mic-projekt/-/commit/dcab778d50a42cf46c2cfc524ed9a8a6dfc84273)) Universumgames on [2024-10-11](## "Fri, 11 Oct 2024 12:20:14 +0200") : add documentation to old functions
- ([977090d](https://git.ide3.de/universumgames/mic-projekt/-/commit/977090d669d159e7c89c76f41ba41f618fb4a8d3)) Universumgames on [2024-10-11](## "Fri, 11 Oct 2024 12:15:12 +0200") : add c++ defines
- ([db985fe](https://git.ide3.de/universumgames/mic-projekt/-/commit/db985fe134a45e243d040f9b517e459f2ab0ca99)) Universumgames on [2024-10-11](## "Fri, 11 Oct 2024 12:13:24 +0200") : Merge branch 'main' of https://git.ide3.de/universumgames/mic-projekt into feature-storage-driver
- ([2f567ef](https://git.ide3.de/universumgames/mic-projekt/-/commit/2f567efe007c04f4614b9447709d4bc9ab30123c)) Universumgames on [2024-10-11](## "Fri, 11 Oct 2024 12:11:25 +0200") : Merge branch 'main' of https://git.ide3.de/universumgames/mic-projekt into feature-lock
- ([9931f20](https://git.ide3.de/universumgames/mic-projekt/-/commit/9931f20de4ddd52e251869402515dfb7914d3078)) Universumgames on [2024-10-11](## "Fri, 11 Oct 2024 12:08:07 +0200") : update
- ([347c21b](https://git.ide3.de/universumgames/mic-projekt/-/commit/347c21ba45c9b00be99ac33ff7ed93204c63c8a5)) Universumgames on [2024-10-11](## "Fri, 11 Oct 2024 10:56:53 +0200") : update sprint plant
- ([bf14abd](https://git.ide3.de/universumgames/mic-projekt/-/commit/bf14abd3396c824e0a6c8f269f00dd2e948c2e85)) simonvehreschild on [2024-10-10](## "Thu, 10 Oct 2024 19:29:05 +0200") : .
- ([ea5a7e1](https://git.ide3.de/universumgames/mic-projekt/-/commit/ea5a7e1002c9454911732ae8c995740adb2b0719)) Universumgames on [2024-10-10](## "Thu, 10 Oct 2024 19:24:14 +0200") : Merge branch 'main' of https://git.ide3.de/universumgames/mic-projekt into feature-lock
- ([6fc471f](https://git.ide3.de/universumgames/mic-projekt/-/commit/6fc471fb72a2c2be37674bcc7b85a9fd1a229f59)) Universumgames on [2024-10-10](## "Thu, 10 Oct 2024 19:18:27 +0200") : cleanup
- ([54b71ee](https://git.ide3.de/universumgames/mic-projekt/-/commit/54b71ee730ee5790b9cf63092c73488652815c77)) simonvehreschild on [2024-10-10](## "Thu, 10 Oct 2024 19:13:25 +0200") : fertig heute
- ([68f2b32](https://git.ide3.de/universumgames/mic-projekt/-/commit/68f2b328128356debdd50cd02a4a2938a7380334)) Universumgames on [2024-10-10](## "Thu, 10 Oct 2024 18:55:41 +0200") : cleanup main
- ([db0439a](https://git.ide3.de/universumgames/mic-projekt/-/commit/db0439a97c8f22e17a9225da34eff1cdf737e2ad)) Universumgames on [2024-10-10](## "Thu, 10 Oct 2024 18:47:19 +0200") : init storage
- ([507f793](https://git.ide3.de/universumgames/mic-projekt/-/commit/507f793d7d097b7c5c343d174cff71f91dfead53)) simonvehreschild on [2024-10-10](## "Thu, 10 Oct 2024 18:45:07 +0200") : test
- ([3147837](https://git.ide3.de/universumgames/mic-projekt/-/commit/314783771a4a90088a60da5e7890c498cd706567)) Universumgames on [2024-10-10](## "Thu, 10 Oct 2024 18:29:53 +0200") : finish sprint plan
- ([63cb417](https://git.ide3.de/universumgames/mic-projekt/-/commit/63cb4178868ae12b7d8d3937a8b783166e38011a)) Universumgames on [2024-10-08](## "Tue, 8 Oct 2024 23:42:35 +0200") : refactoring
- ([996f363](https://git.ide3.de/universumgames/mic-projekt/-/commit/996f363341a3c6da0cee2731337704389c1c27d9)) Universumgames on [2024-10-08](## "Tue, 8 Oct 2024 23:14:28 +0200") : fix led strip
- ([d45b229](https://git.ide3.de/universumgames/mic-projekt/-/commit/d45b2295a0eb170171839f1d37a71f3d3e5174ad)) Universumgames on [2024-10-08](## "Tue, 8 Oct 2024 23:14:13 +0200") : update backlog
- ([3071cb3](https://git.ide3.de/universumgames/mic-projekt/-/commit/3071cb310f6f44ce29257fd1df81dfe80893ed52)) Universumgames on [2024-10-07](## "Mon, 7 Oct 2024 18:26:50 +0200") : update backlog
- ([df5efa3](https://git.ide3.de/universumgames/mic-projekt/-/commit/df5efa3148215291224b605842a2d348f63dc7fc)) Universumgames on [2024-10-07](## "Mon, 7 Oct 2024 16:11:52 +0200") : update
- ([3aeae96](https://git.ide3.de/universumgames/mic-projekt/-/commit/3aeae960c54b79cb2c10e4bea0c93d2bcbe1bdeb)) Universumgames on [2024-10-07](## "Mon, 7 Oct 2024 14:09:20 +0200") : add datasheets
- ([695ad82](https://git.ide3.de/universumgames/mic-projekt/-/commit/695ad827ad9d430184201c1081f256d5739a4c5c)) Universumgames on [2024-10-07](## "Mon, 7 Oct 2024 13:05:32 +0200") : bugfixes
- ([b26a7b9](https://git.ide3.de/universumgames/mic-projekt/-/commit/b26a7b936ae7422189c8e334d95813fc6c68651e)) Universumgames on [2024-10-06](## "Sun, 6 Oct 2024 18:22:10 +0200") : play around with hardware led
- ([555a7f9](https://git.ide3.de/universumgames/mic-projekt/-/commit/555a7f9bf95e6733e1f0850702df2c42b7ab6a6e)) Universumgames on [2024-10-06](## "Sun, 6 Oct 2024 18:21:58 +0200") : add cpp formatting config
- ([f350323](https://git.ide3.de/universumgames/mic-projekt/-/commit/f3503238b54a6d8812431f5e7c18ed6a7ede67c8)) Universumgames on [2024-10-06](## "Sun, 6 Oct 2024 18:21:03 +0200") : test assembler
- ([a86c7cd](https://git.ide3.de/universumgames/mic-projekt/-/commit/a86c7cde54f8de6152c31b819bc491b360a9c9ce)) Universumgames on [2024-10-06](## "Sun, 6 Oct 2024 13:12:30 +0200") : update Serial, switch to cpp
- ([0b6cadd](https://git.ide3.de/universumgames/mic-projekt/-/commit/0b6cadd1ac37331de55ecb0b112c2a9c4c76b103)) Universumgames on [2024-10-05](## "Sat, 5 Oct 2024 16:57:41 +0200") : first serial test
- ([ebe6fad](https://git.ide3.de/universumgames/mic-projekt/-/commit/ebe6fadfd2ed63880dd0925bc9eb1d092a9a5e8b)) Universumgames on [2024-10-04](## "Fri, 4 Oct 2024 19:35:29 +0200") : switch to platformio
- ([7ed0768](https://git.ide3.de/universumgames/mic-projekt/-/commit/7ed07680d3e5fbe5f452daadd767fc426f2bc098)) Universumgames on [2024-10-04](## "Fri, 4 Oct 2024 16:52:42 +0200") : update
- ([acad8d8](https://git.ide3.de/universumgames/mic-projekt/-/commit/acad8d85c8d9bfdc56828f987b81d672290a3870)) Tom Arlt on [2024-10-04](## "Fri, 4 Oct 2024 13:24:20 +0000") : Add LICENSE
- ([0f9c7bb](https://git.ide3.de/universumgames/mic-projekt/-/commit/0f9c7bb8ca9151e02d2eef3496b29e4e9596e993)) Universumgames on [2024-10-04](## "Fri, 4 Oct 2024 15:22:45 +0200") : init
- ([90f8b42](https://git.ide3.de/universumgames/mic-projekt/-/commit/90f8b4222daad974fd31f07dc483515db23cfd74)) Tom Arlt on [2024-10-04](## "Fri, 4 Oct 2024 13:12:12 +0000") : Initial commit

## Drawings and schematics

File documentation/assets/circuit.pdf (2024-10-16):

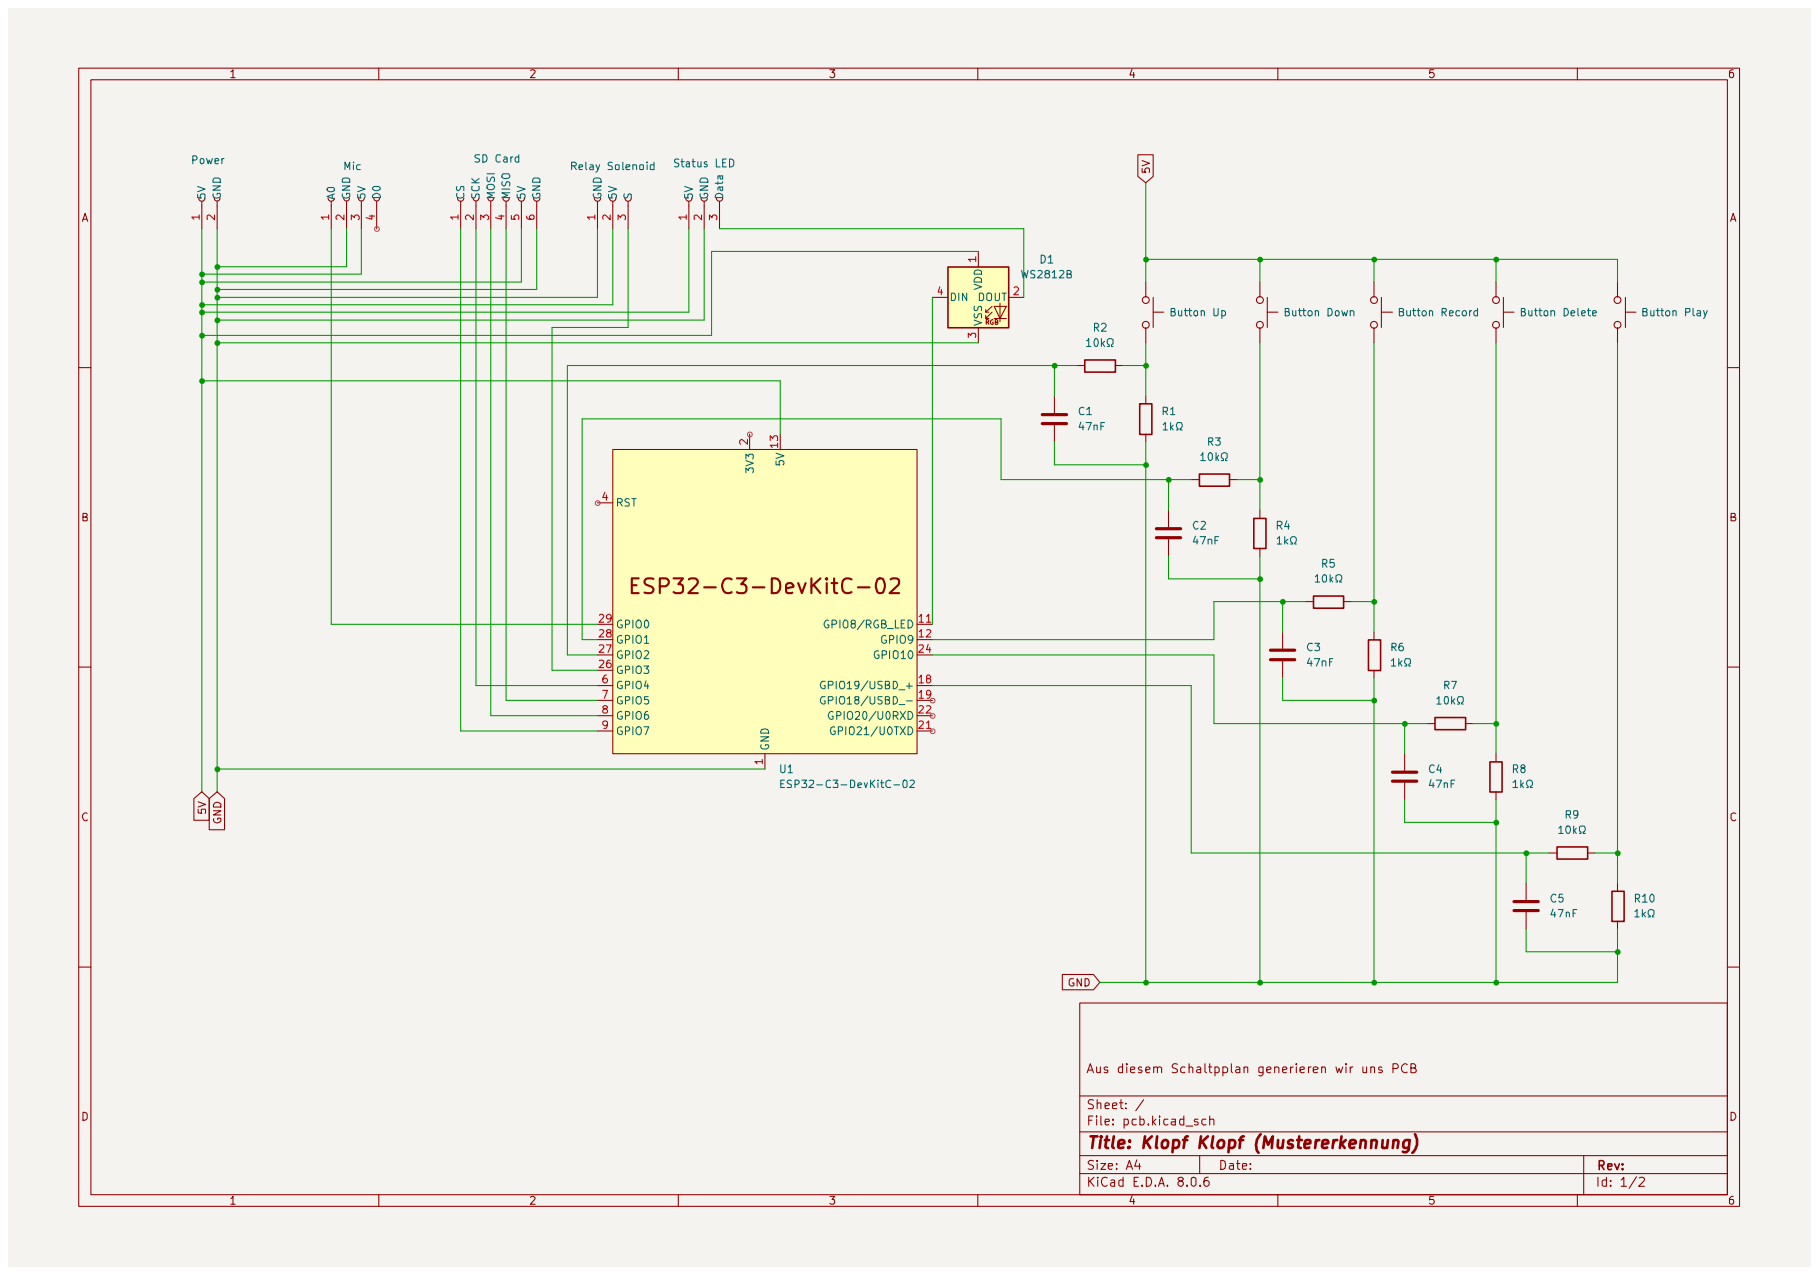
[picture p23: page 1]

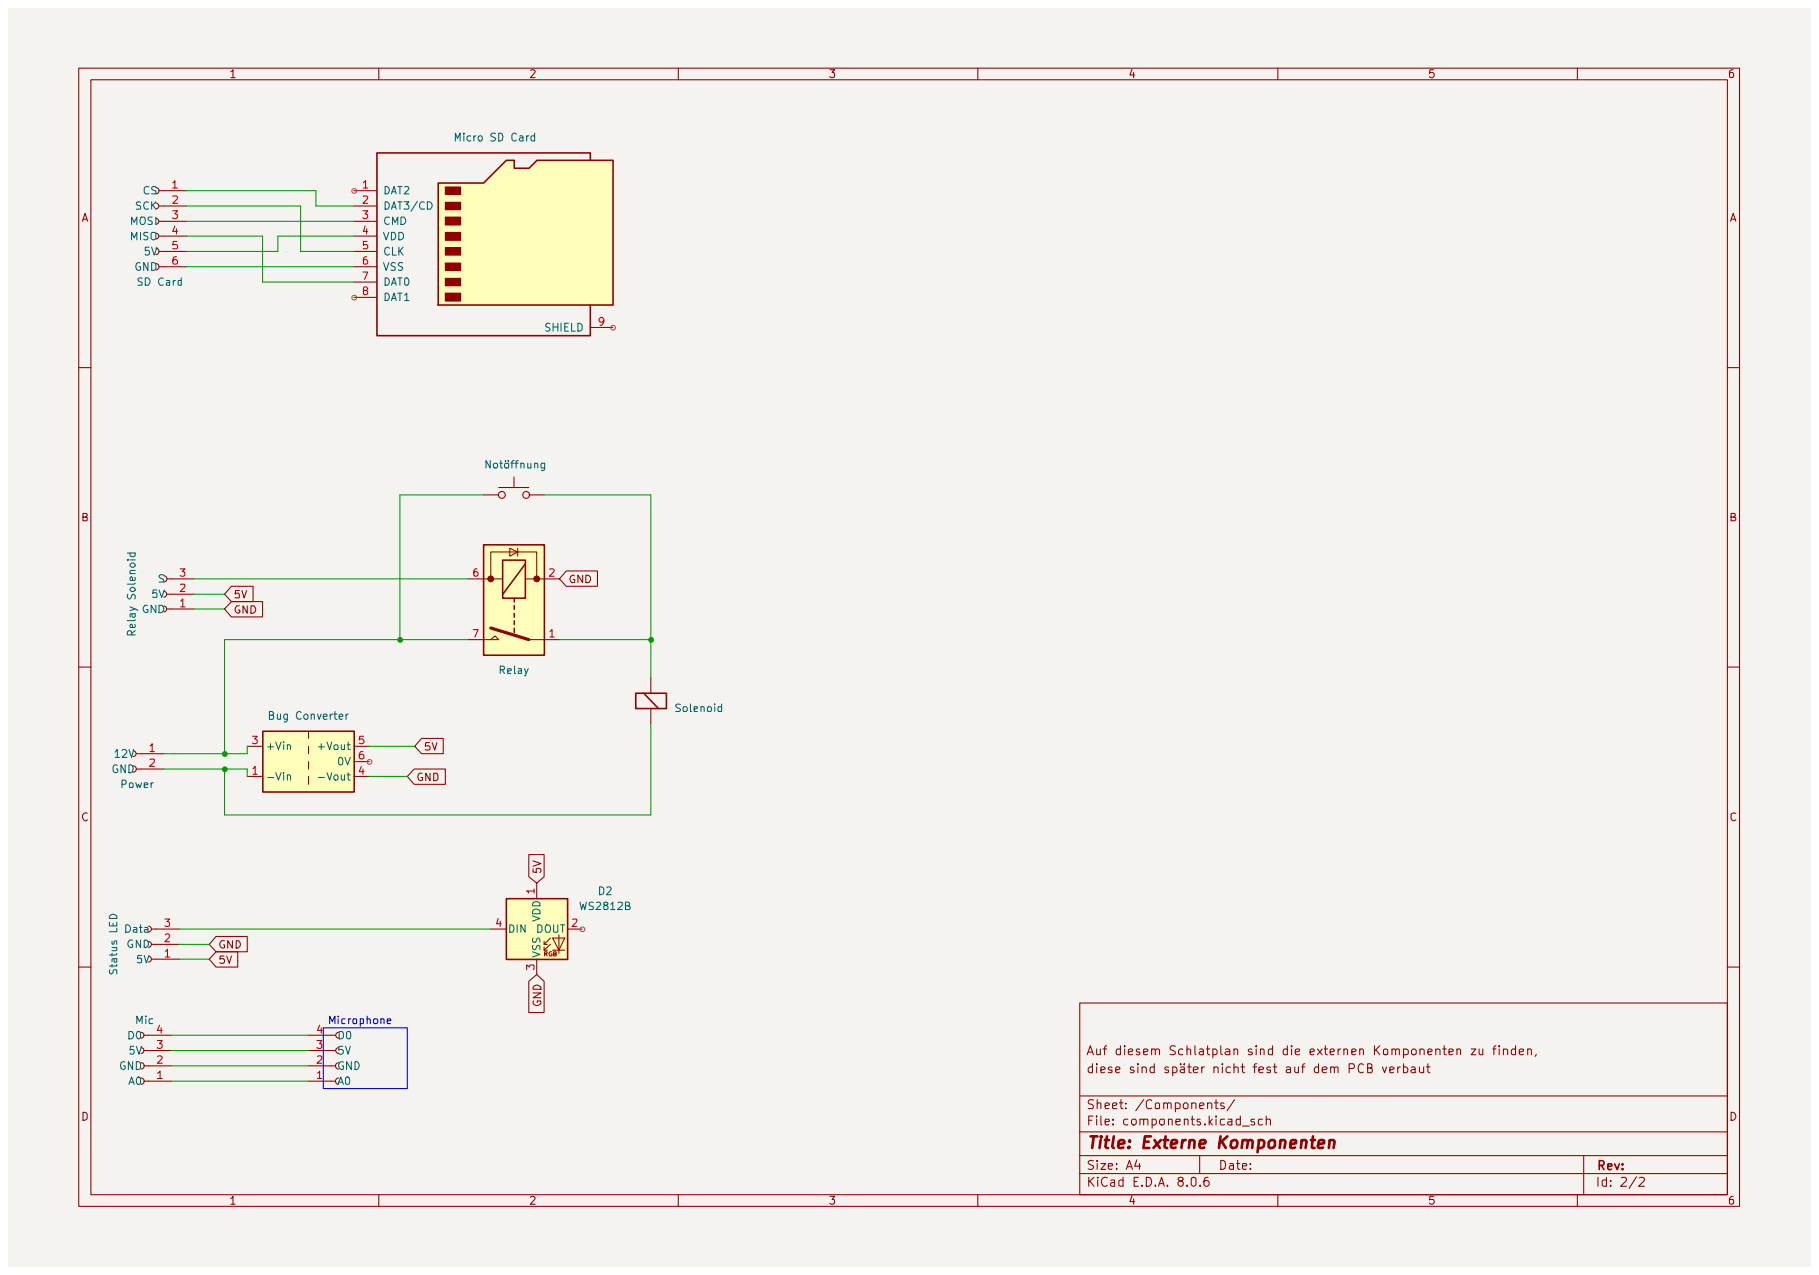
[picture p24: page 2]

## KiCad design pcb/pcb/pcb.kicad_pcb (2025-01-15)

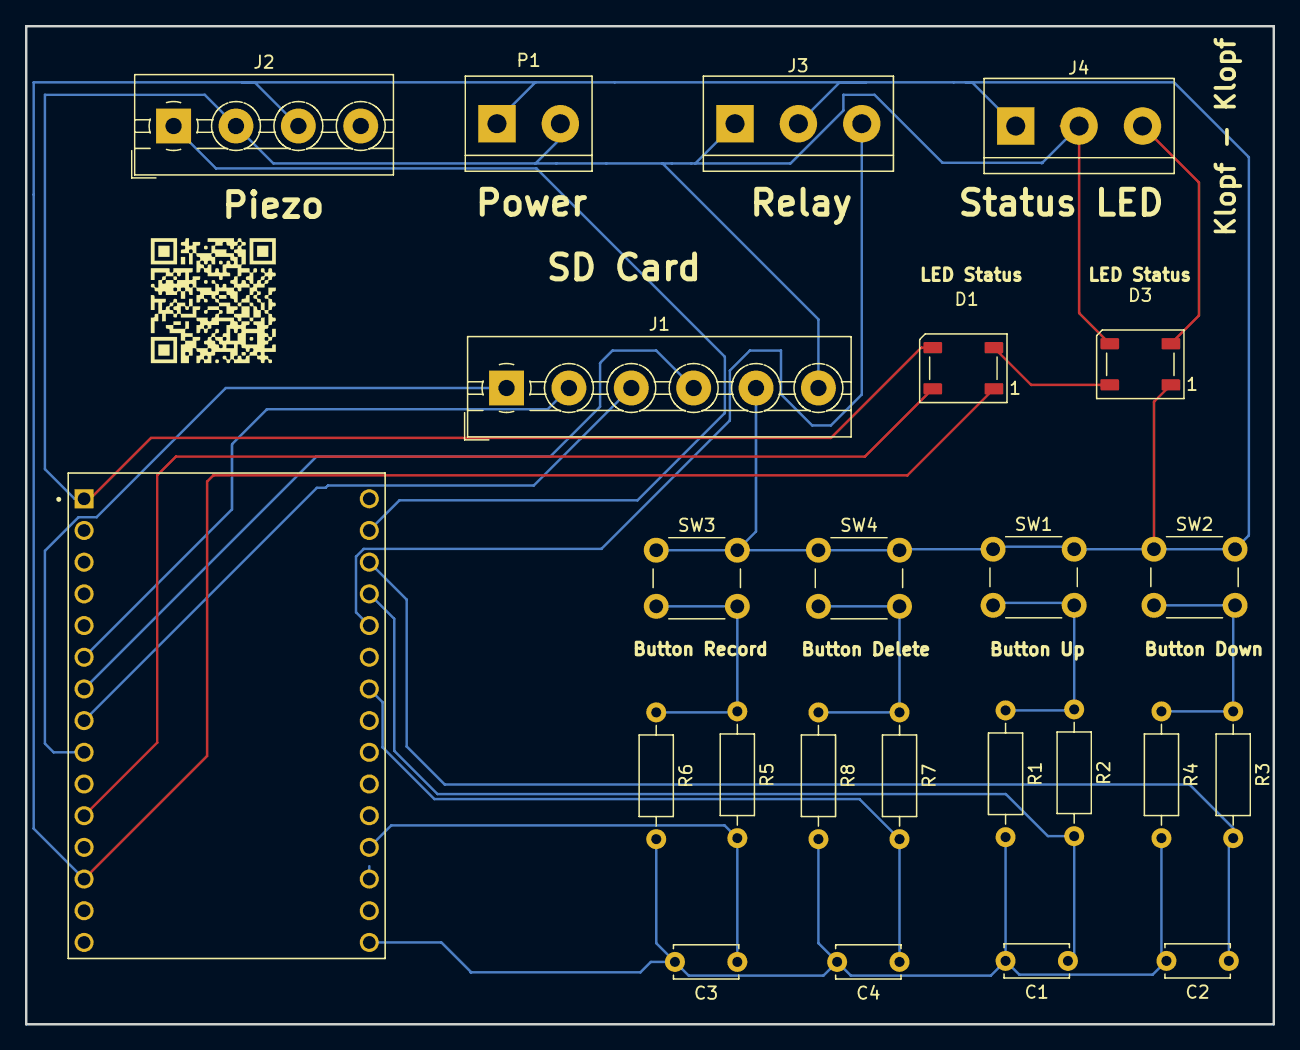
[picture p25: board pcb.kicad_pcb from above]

Board: 2 copper layers, 100.0 x 80.0 mm, 24 parts (0 on the bottom side), 20 nets.

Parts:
C1, C2, C3, C4: 47nF; C_Disc_D5.0mm_W2.5mm_P5.00mm
D1, D3: WS2812B; LED_WS2812B_PLCC4_5.0x5.0mm_P3.2mm
J1: SD Card; TerminalBlock_MaiXu_MX126-5.0-06P_1x06_P5.00mm
J2: Mic; TerminalBlock_MaiXu_MX126-5.0-04P_1x04_P5.00mm
J3: Relay Solenoid; TerminalBlock_bornier-3_P5.08mm
J4: Status LED; TerminalBlock_bornier-3_P5.08mm
P1: Power; TerminalBlock_bornier-2_P5.08mm
R1, R4, R6, R8: 1kΩ; R_Axial_DIN0207_L6.3mm_D2.5mm_P10.16mm_Horizontal
R2, R3, R5, R7: 10kΩ; R_Axial_DIN0207_L6.3mm_D2.5mm_P10.16mm_Horizontal
SW1: Button Up; SW_PUSH_6mm_H4.3mm
SW2: Button Down; SW_PUSH_6mm_H4.3mm
SW3: Button Record; SW_PUSH_6mm_H4.3mm
SW4: Button Delete; SW_PUSH_6mm_H4.3mm
U1: ESP32-C3-DevKitC-02; XCVR_ESP32-C3-DEVKITC-02

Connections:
3V3: U1.2 (3V3), U1.3 (3V3)
5V: D1.1 (VDD), D3.1 (VDD), J1.5 (5V), J2.3 (5V), J3.2 (5V), J4.1 (5V), P1.1 (5V), SW1.1, SW2.1, SW3.1, SW4.1, U1.13 (5V), U1.14 (5V)
GND: C1.2, C2.2, C3.2, C4.2, D1.3 (VSS), D3.3 (VSS), J1.6 (GND), J2.2 (GND), J3.1 (GND), J4.2 (GND), P1.2 (GND), R1.2, R4.2, R6.2, R8.2, U1.1 (GND), U1.5 (GND), U1.10 (GND), U1.15 (GND), U1.16 (GND), U1.17 (GND), U1.20 (GND), U1.23 (GND), U1.25 (GND), U1.30 (GND)
unnamed: D1.4 (DIN), U1.11 (GPIO8/RGB_LED)
unnamed: D1.2 (DOUT), D3.4 (DIN)
unnamed: D3.2 (DOUT), J4.3 (Data)
unnamed: J1.1 (CS), U1.9 (GPIO7)
unnamed: J1.4 (MISO), U1.7 (GPIO5)
unnamed: J1.3 (MOSI), U1.8 (GPIO6)
unnamed: J1.2 (SCK), U1.6 (GPIO4)
unnamed: J2.1 (A0), U1.29 (GPIO0)
unnamed: J3.3 (S), U1.26 (GPIO3)
unnamed: R1.1, R2.1, SW1.2
unnamed: R3.1, R4.1, SW2.2
unnamed: R5.1, R6.1, SW3.2
unnamed: R7.1, R8.1, SW4.2
unnamed: C2.1, R3.2, U1.28 (GPIO1)
unnamed: C1.1, R2.2, U1.27 (GPIO2)
unnamed: C4.1, R7.2, U1.24 (GPIO10)
unnamed: C3.1, R5.2, U1.19 (GPIO18/USBD_-)

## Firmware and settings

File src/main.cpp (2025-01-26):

#include <freertos/FreeRTOS.h>
#include <freertos/task.h>

#include "HardwareLED.h"
#include "PatternManagement.h"
#include "PatternRecorder.h"
#include "PatternStorage.h"
#include "Serial.h"
#include "Storage.h"
#include "_AnalogRead_internal.h"
#include "basicDefs.h"
#include "lock_open.h"
#include "lock_status.h"

#include <CommandLine.h>

#define ECHO_TASK_STACK_SIZE 2048

CPP_BEGIN void app_main() {
    esp_log_level_set("*", ESP_LOG_INFO);
    printf("Running version %s\n", VERSION_HASH);
    beginSerial(CONFIG_MONITOR_BAUD);
    initCommandLine();

    initialize_lock_state();

    bool ptStor = initPatternStorage();
    if (!ptStor) {
        ESP_LOGE("main", "Failed to initialize pattern storage");
        esp_restart();
    }

    ESP_LOGV("main", "Log test verbose");
    ESP_LOGD("main", "Log test debug");
    ESP_LOGI("main", "Log test info");
    ESP_LOGW("main", "Log test warn");
    ESP_LOGE("main", "Log test error");

    initPatternRecorder();
    // initPatternManagement();
}

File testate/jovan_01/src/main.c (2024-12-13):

#include "Serial.h"


int app_main(){
    initSerial();

    int erste = 0;
    scanf("%d", &erste);
        if (erste == 1)
        {
            printf("Jovan arnaut\n");
        }


    int zweite = 1;
    scanf("%d", &zweite);
        if (zweite != 1)
        {
            printf("%2x\n", zweite);
        }


    int dritte = 0;
    int primenumbers[54] = {2, 3, 5, 7, 11, 13, 17, 19, 23, 29, 31, 37, 41, 43, 47, 53, 59, 61, 67, 71, 73, 79, 83, 89, 97, 101, 103, 107, 109, 113, 127, 131, 137, 139, 149, 151, 157, 163, 167, 173, 179, 181, 191, 193, 197, 199, 211, 223, 227, 229, 233, 239, 241, 251};
    scanf("%d", &dritte);
        if (dritte > 5 || dritte < 255)
        {
            for (int i = 0; i < 50; i++)
            {
                if (primenumbers[i] > dritte)
                {
                    printf("%d\n", primenumbers[i]);
                    break;
                }
            }
        }


    char monthdays[12] = {31, 28, 31, 30, 31, 30, 31, 31, 30, 31, 30, 31};
    char vier1[32];
    char vier2[32];
    scanf("%s", vier1);
    scanf("%s", vier2);

    int day = 0;
    int month = 0;
    int gesamt = 0;

    for (int i = 0; i < 31; i++)
    {
        if (vier1[i] == '*')
        {
            day++;
        }
        if (vier2[i] == '.')
        {
            month++;
        }
    }

    for (int i = month ; i <= 12; i++)
    {   
        if (i == month)
        {
            gesamt = gesamt + (monthdays[i-1] - day);
        }
        else
        {   
            if (i == 12)
            {
                gesamt = gesamt + 25;
                break;
            }
            gesamt = gesamt + monthdays[i-1];
        }
        
    }
    printf("%d\n", gesamt);
    
    char funf[2];
    scanf("%s", funf);
    int diff = 'J' - funf[0];
    char verschob[6] = "Jovan";
    for (int i = 0; i < 5; i++)
    {
        verschob[i] = verschob[i] - diff;
    }

    printf("%s\n", verschob);

    char sechs[2];
    scanf("%s", sechs);
    if (sechs[0] == '?')
    {
        printf("Das Projekt macht richtig viel Spaß, viel besser als eine stumpfe Klausur :D\n");
    }
    
    
    return 0;
}

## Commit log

2024-10-04 switch to platformio
2024-10-06 update Serial, switch to cpp
2024-10-06 test assembler
2024-10-06 play around with hardware led
2024-10-08 fix led strip
2024-10-11 implement storage driver first part
    [littlefs.csv]
2024-10-13 finish basic storage driver
2024-10-14 add pcb
    [components.kicad_sch, pcb.kicad_pcb, pcb.kicad_sch]
2024-10-14 update pcd mit Notöffnung
    [components.kicad_sch, pcb.kicad_sch]
2024-10-16 update assets and schematic
    [components.kicad_sch, pcb.kicad_sch]
2024-10-17 update-README-und-Text-Präsentation
2024-10-18 add testing framework and fix string methods
    [main.cpp]
2024-10-20 add error handling to mounting
2024-10-22 try fixing led
2024-10-22 try fixing LED driver with spi control, not usable because overwriting storage bus
2024-10-22 add led spi explanation image
2024-10-24 update cpp header pragma
    [littlefs.csv]
2024-10-27 fix pattern storage driver and write tests
2024-10-27 implement max function as assembler, add support for platform specific assembler
2024-10-27 in assembly differentiate between arm and x64
2024-10-27 fix comments in assembly
2024-10-28 fix platform specific assembler
2024-10-28 retest native assembly
2024-10-29 not using x64 assembly
2024-10-30 fix ci stage test
2024-10-30 Resolve "Muster einspeichern"
    [issues.csv]
2024-10-30 update comments, add code check to cicd
    [huge_app.csv]
2024-11-01 lib extern led first attempt
2024-11-02 update, Anpassungen der Hinweise
2024-11-04 update pcb
    [components.kicad_sch, pcb.kicad_sch]
2024-11-04 start implementing encoder
2024-11-06 use pattern encoder
2024-11-07 clang tidy warnings fix, add ring buffer
    [main.cpp]
2024-11-07 missing partition table
    [huge_app.csv]
2024-11-07 ring buffer fixes and added tests
    [main.cpp]
2024-11-07 add thread prio header
2024-11-07 continue with pattern encoder
2024-11-07 encoder tests
2024-11-07 add gitignore for old encoder tests
2024-11-11 PCB update
    [components.kicad_sch, pcb.kicad_pcb, pcb.kicad_sch]
2024-11-11 verkabelung fertig
    [pcb.kicad_pcb]
2024-11-15 use global pin definition
2024-11-15 update pattern encoder
2024-11-17 fix esp assembly
2024-11-17 add assembly comments
2024-11-18 Finish 100x80
    [pcb.kicad_pcb]
2024-11-18 FertigEndgültig100x80mm
    [pcb-B_Cu.gbr, pcb-B_Mask.gbr, pcb-B_Paste.gbr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]
2024-12-04 fix assembler conventions
2024-12-13 Simon und Jovan
2025-01-13 update gitignore for kicad
2025-01-13 Change PCB/TEST
    [pcb.kicad_pcb]
2025-01-14 Finale Change PCB
    [pcb.kicad_pcb]
2025-01-24 adding pattern encoder reset debug log
2025-01-25 update 3d prints
    [Harken_Door_Lock.stl, LOGO_MIC.stl, Platinen_Socket_OPV.stl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]
2025-01-26 renaming 3d print files
    [angle_mount_fake_floor.stl, circuit_clamp_amplifier.stl, circuit_clamp_main.stl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]
